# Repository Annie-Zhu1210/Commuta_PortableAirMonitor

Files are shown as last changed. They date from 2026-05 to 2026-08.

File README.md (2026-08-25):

# Commuta — A Portable IoT Air Quality Monitor

**A wearable, battery-powered device that measures your personal air quality on the go — built to capture fine-particle (PM) exposure during everyday journeys on the London Underground.**






<p align="center">
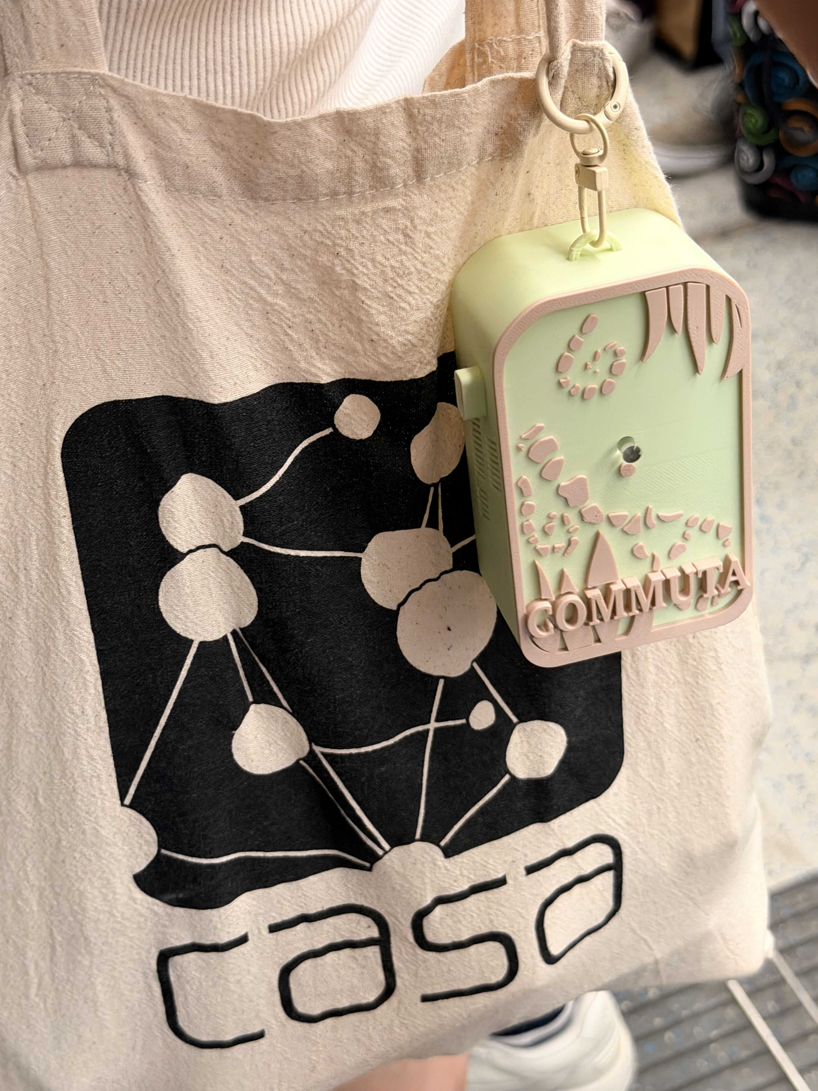
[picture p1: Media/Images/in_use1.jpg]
Commuta device
  
</p>

---

## Overview

Commuta is a compact, self-contained air quality monitor designed to be carried through a daily commute. Most air quality data comes from fixed street-level stations, which say little about what a person actually breathes underground, on a platform, or inside a carriage. Commuta closes that gap: it logs particulate matter and supporting environmental readings continuously as you travel, then streams the data to a companion iOS app over Bluetooth Low Energy.

The result is a personal, location-aware record of exposure — the kind of data that lets you see, for example, how a deep, older Underground line compares to a sealed, modern one.

## Key Features

- **Personal PM monitoring** — measures PM1, PM2.5, PM4 and PM10 with a laser particle sensor.
- **Full environmental context** — also logs CO₂, temperature, humidity, VOC and NOx indices, and barometric pressure.
- **Fully portable** — runs off an onboard rechargeable LiPo battery, no wires or phone tether needed to collect data.
- **On-device logging** — data is buffered to flash storage, so nothing is lost if the phone is out of range.
- **BLE companion app** — a Flutter iOS app with a live air quality score, per-pollutant bands and health advice, maps, history charts, and CSV export ([full feature list](commuta_app#features)).
- **Discreet by design** — a custom 3D-printed enclosure and minimal indicator LEDs, intended to be worn unobtrusively.

## How It Works

Commuta is a three-part system: the **device** senses and logs, the **app** receives and tags, and the **analysis pipeline** turns raw logs into exposure insights.

<p align="center">
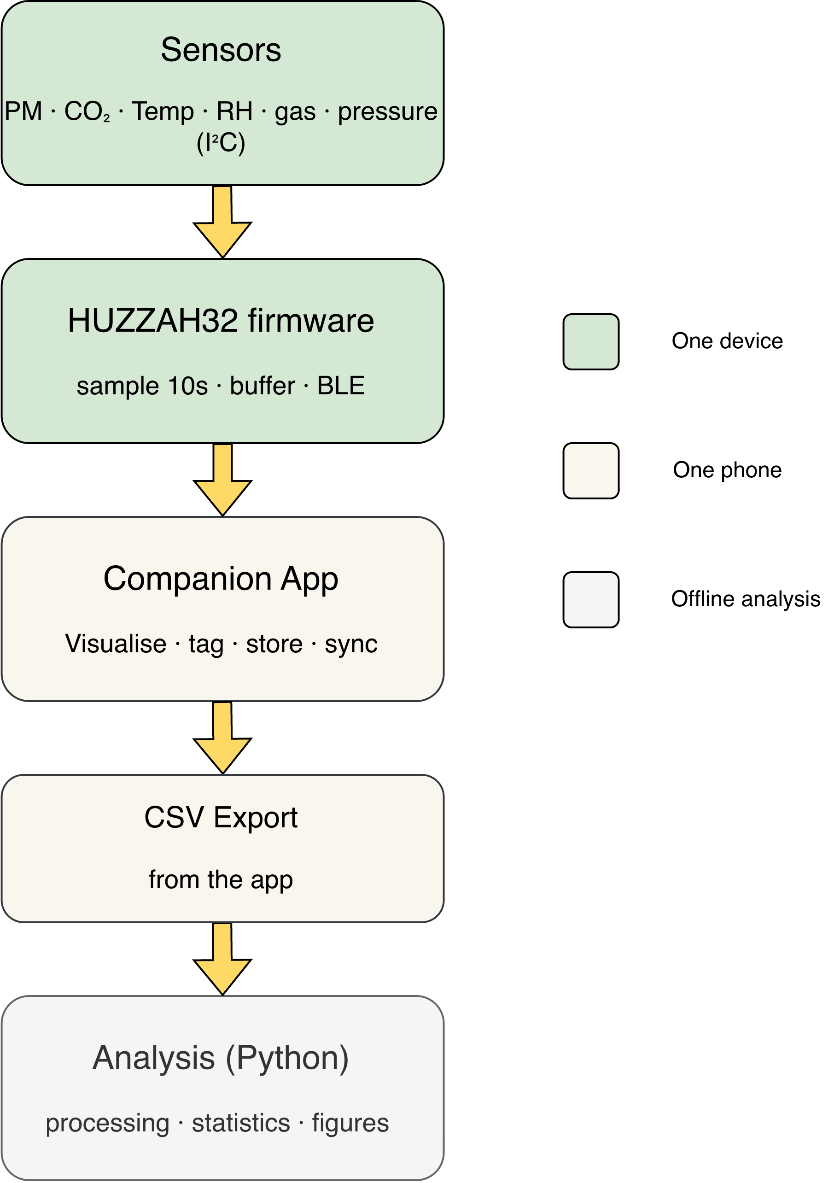
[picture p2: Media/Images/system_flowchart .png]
System architecture
  
</p>

## Hardware

The device is built around an ESP32 microcontroller with a stack of I²C sensors and a boosted power supply for the particle sensor.

| Component | Part | Role |
|---|---|---|
| Microcontroller | Adafruit HUZZAH32 (ESP32) | Sensing, logging, BLE |
| Particulate matter | Sensirion **SPS30** | PM1 / PM2.5 / PM10 |
| CO₂ & climate | Sensirion **SCD40** | CO₂, temperature, humidity |
| Gas indices | Sensirion **SGP41** | VOC index, NOx index |
| Pressure | Infineon **DPS368** | Barometric pressure |
| Power | 2000 mAh LiPo + MT3608 boost | Portable supply (5 V for the SPS30) |

<p align="center">
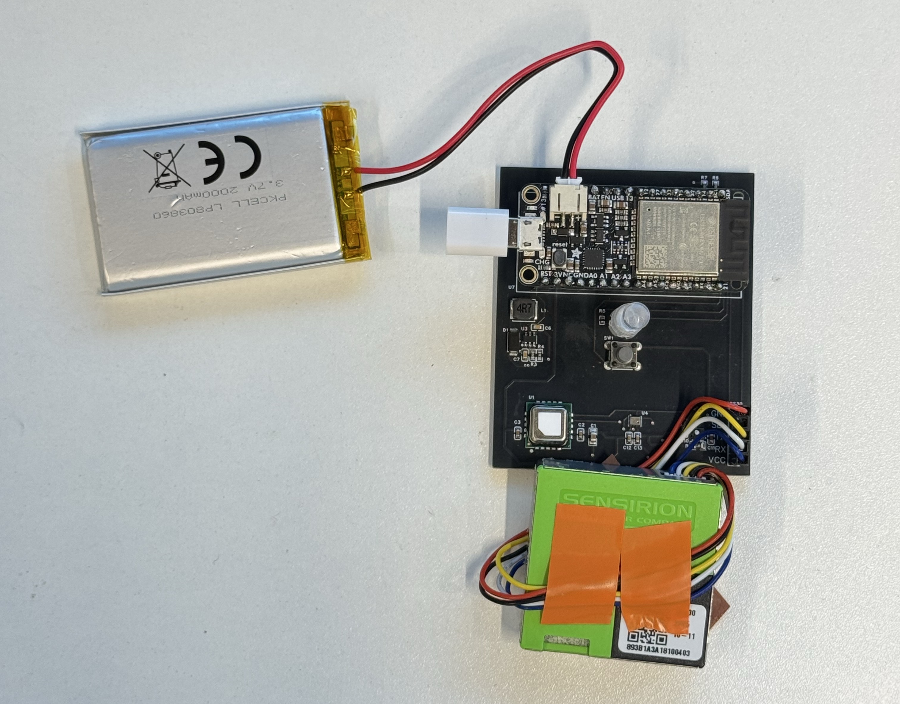
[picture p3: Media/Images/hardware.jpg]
Assembled hardware
  
</p>

## Enclosure

A custom enclosure houses the electronics and battery in a wearable form factor. CAD and printable files live in [`/enclosure`](enclosure).

<p align="center">
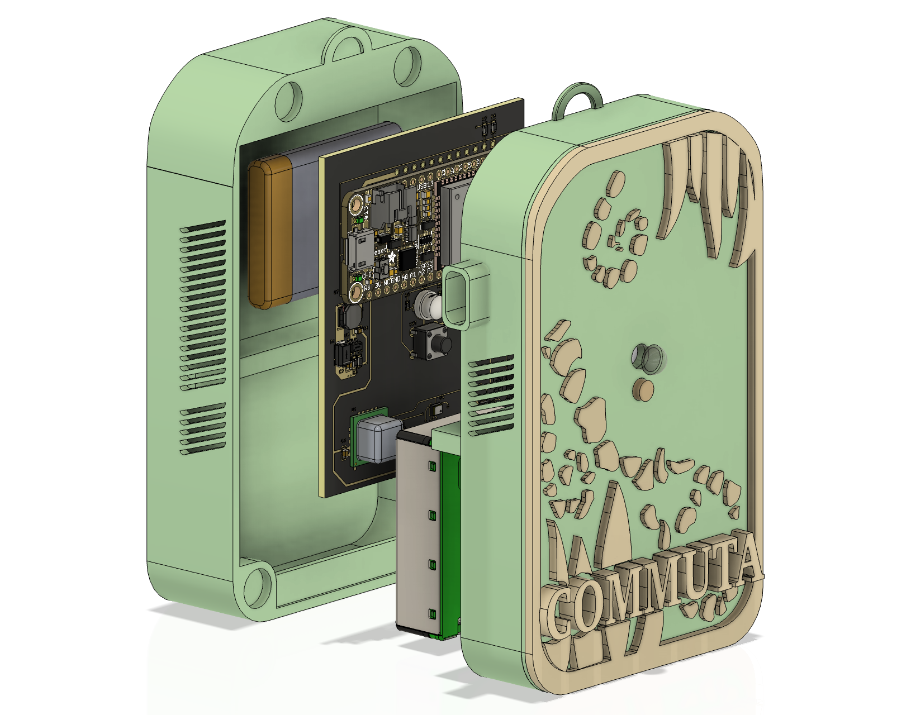
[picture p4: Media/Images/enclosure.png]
Enclosure
  
</p>

## Repository Structure

| Folder | Contents |
|---|---|
| [`Device/`](Device) | `Commuta_code/`: main device firmware — sensor drivers, logging, and BLE communication (C++ / Arduino). `PCB/`: schematic and PCB gerber files. Plus the [Button & LED reference](Device/Button%26LED.md). |
| [`commuta_app/`](commuta_app) | The Flutter iOS companion app. **See its own [README](commuta_app) for features, architecture, and setup.** |
| [`enclosure/`](enclosure) | 3D-printable enclosure — see its [README](enclosure) for what to print and the design history. |
| [`data/`](data) | Field-study dataset: untouched raw device exports and a fully reproducible raw → clean pipeline — see its [README](data). |
| [`visualisation/`](visualisation) | Analysis scripts and figures for the Underground PM2.5 case study — see its [README](visualisation) for the script → figure map. |
| [`Battery/`](Battery) | LiPo battery discharge characterisation — data, script, and [report](Battery/battery_report.md). |
| [`test_SPS30/`](test_SPS30) | Standalone bring-up sketch for the SPS30 particle sensor. |
| [`test_PMS5003/`](test_PMS5003) | Early sensor evaluation sketch (PMS5003). |
| [`Media/`](Media) | Photos, diagrams, and figures. |

## Getting Started

### Device firmware
1. Open the sketch in [`Device/Commuta_code/`](Device/Commuta_code) with the Arduino IDE.
2. Install the ESP32 board package and the required Sensirion sensor libraries.
3. Copy `secrets_example.h` to `secrets.h` and generate your own BLE UUIDs (instructions inside the file). The same UUIDs go into the app's `ble_uuids.dart`.
4. Select the **Adafruit HUZZAH32 (ESP32)** board, connect over USB, and flash.

### Companion app
The iOS app is in [`commuta_app/`](commuta_app). Build and setup instructions are documented in that folder's README.

## Case Study: PM2.5 on the London Underground

As its first real-world deployment, Commuta was carried across six London Underground lines to study how line type and platform ventilation design affect commuters' PM2.5 exposure. The full chain is in this repo and is reproducible end to end:

1. **Collect** — the device logs readings during journeys; the app tags stations and exports CSVs.
2. **Clean** — [`data/`](data) holds the untouched raw exports and a rule-driven pipeline (`python data/process_data.py`) that regenerates the clean dataset from them.
3. **Analyse** — [`visualisation/`](visualisation) turns the clean data into the study's figures (`python visualisation/step0_dataprep.py`, then any figure script).

<p align="center">
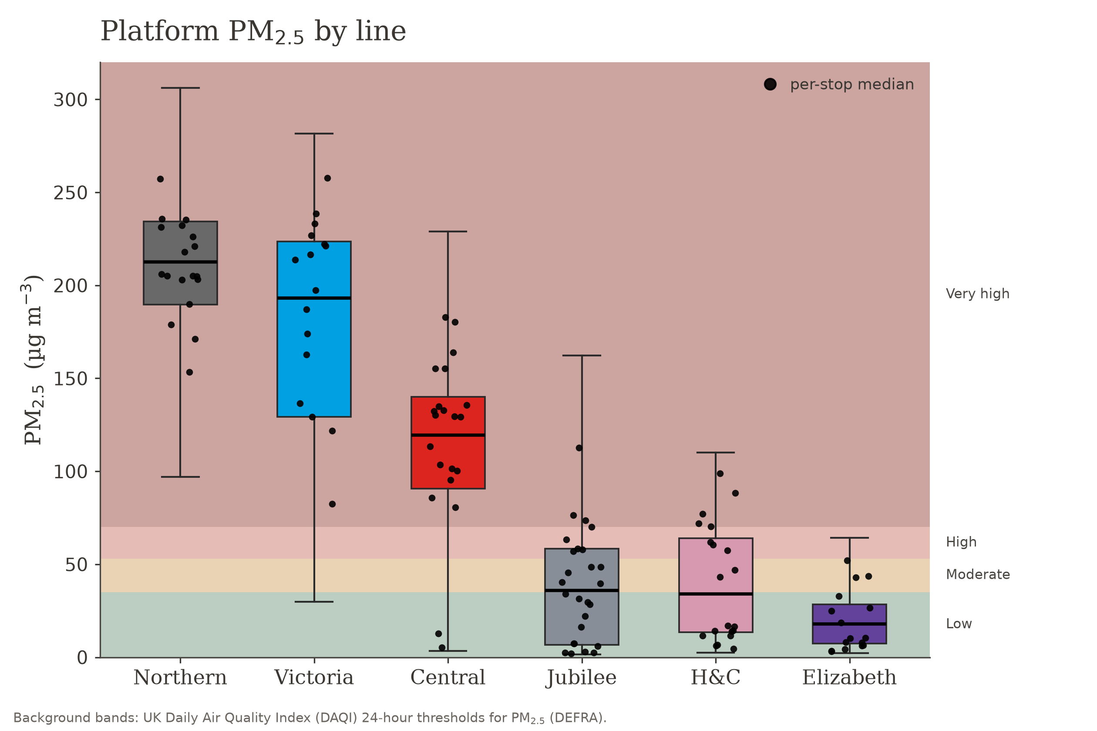
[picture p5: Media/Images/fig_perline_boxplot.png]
Platform PM2.5 exposure comparison across Underground lines
  
</p>

## About the Project

Commuta was developed by Annie Zhu as a prototype on the **Connected Environments** programme at **UCL's Centre for Advanced Spatial Analysis (CASA)**; the Underground case study above formed the research component.

🔗 **Project site:** https://annie-zhu1210.github.io/commuta

## Acknowledgements

- Sensor integration benefited from technical guidance from Sensirion support.

---

<p align="center"><i>Built by Annie Zhu · UCL CASA</i></p>

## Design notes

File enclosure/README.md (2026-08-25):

# Commuta Enclosure

3D-printable enclosure for the Commuta device — a compact, wearable case that houses the ESP32, sensor stack, boost converter, and 2000 mAh LiPo battery, with openings for airflow to the particle sensor, the USB-C charging port, and the single control button.

<p align="center">
  Commuta enclosure
</p>

## What to print

Everything you need for a complete enclosure is in [`final_version/`](final_version):

| File | Part |
|---|---|
| `FinalVersion_Top.stl` | Top shell |
| `FinalVersion_Bottom.stl` | Bottom shell |
| `ButtonCover3.stl` | Button cap for the power/status button |
| `TypeC.stl` | USB-C port cover |
| `FinalVersion_浮雕.3mf` | Embossed (relief) logo variant of the shell — a multi-body 3MF for printing the raised Commuta wordmark, e.g. in a second colour |

The `.3mf` file preserves the separate relief bodies, so open it in your slicer directly (rather than converting to STL) if you want to assign the embossed text its own colour or material.

Printed in PLA with standard settings; no supports are required for the shells in their natural print orientation. The two shells close around the electronics, so check the fit of your assembled stack before committing to long prints.

## Design history

Folders `version1/` through `version9/` document the design's evolution and are kept for reference — none of them are needed to build the device:

- **version1–2** — first fit tests: single shell, then a split top/bottom design.
- **version3** — confirmed the approximate dimensions and necessary openings.
- **version4–5** — tested connection configurations using two sets and four sets of magnets, respectively.
- **version6** — refined shells plus the first embossed-logo (浮雕) experiments as separate relief bodies.
- **version7-10** — button cap and adaptor cover iterations; adjusted button and LED openings dimensions.

## Related

- [Hardware overview](../README.md#hardware) — what goes inside
- [Button & LED reference](../Device/Button%26LED.md) — how the single button and bi-colour LED work

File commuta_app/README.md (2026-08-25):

# Commuta App

**The companion app for the Commuta portable air quality monitor — live readings, maps, history, and health guidance, built with Flutter.**






The Commuta app pairs with the Commuta device over Bluetooth Low Energy and turns its raw sensor stream into something you can act on: an at-a-glance air quality score, per-pollutant bands and health advice, a map of where you breathed what, and a browsable history of every journey.

<p align="center">
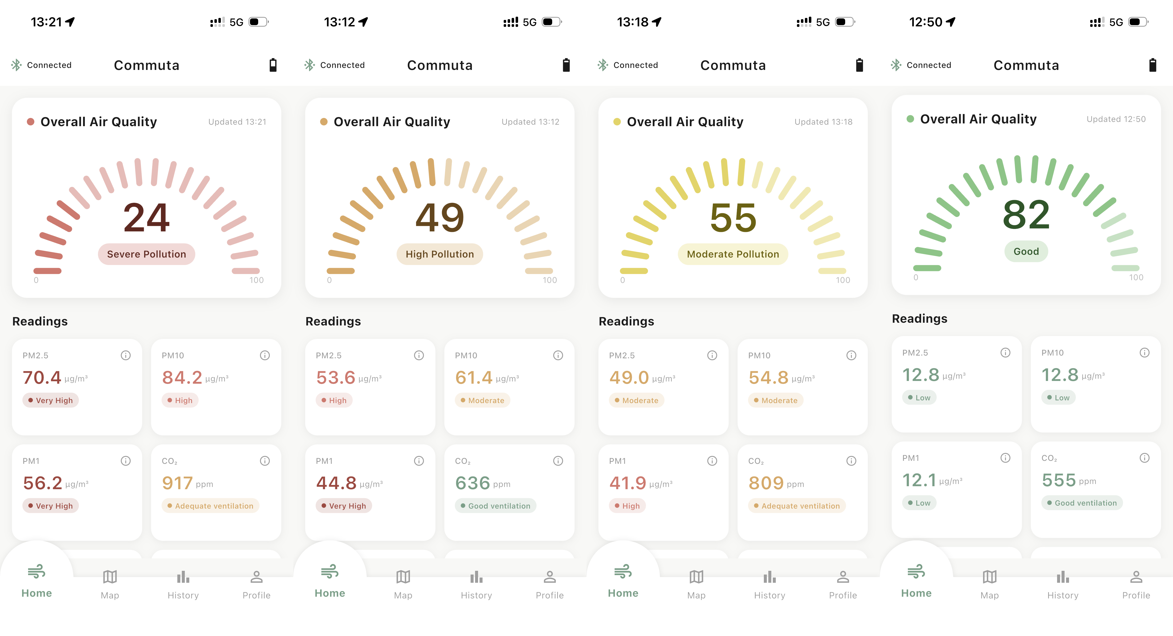
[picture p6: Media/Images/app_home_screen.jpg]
Commuta app Home screen
  
</p>

---

## Features

### Live monitoring (Home)

- **Hero Score** — a single 0–100 score (higher is cleaner) summarising the current reading, with a colour-coded arc gauge and a plain-English descriptor (*Good*, *Moderate Pollution*, *High Pollution*, *Severe Pollution*). The score follows the worst-metric-drives-the-score principle used by the UK DAQI and US EPA AQI. The full algorithm is documented in [`docs/hero_score_algorithm.md`](docs/hero_score_algorithm.md).
- **Live metric cards** for every sensor channel: PM1, PM2.5, PM4, PM10, CO₂, temperature, humidity, barometric pressure, VOC index, and NOx index.
- **Band scales** — each pollutant card shows where the current value sits on its own band scale (*Low / Moderate / High / Very High*), aligned with UK DAQI band boundaries.
- **Health recommendations** — tapping the ⓘ on a metric card opens an info sheet explaining what the metric is and what to do at the current level, updating live as new readings arrive.
- **Local context cards** — the nearest **UK DAQI** value from the London Air Quality Network (LAQN) and current **local weather** from OpenWeather, so device readings can be compared against the official outdoor picture.

<p align="center">
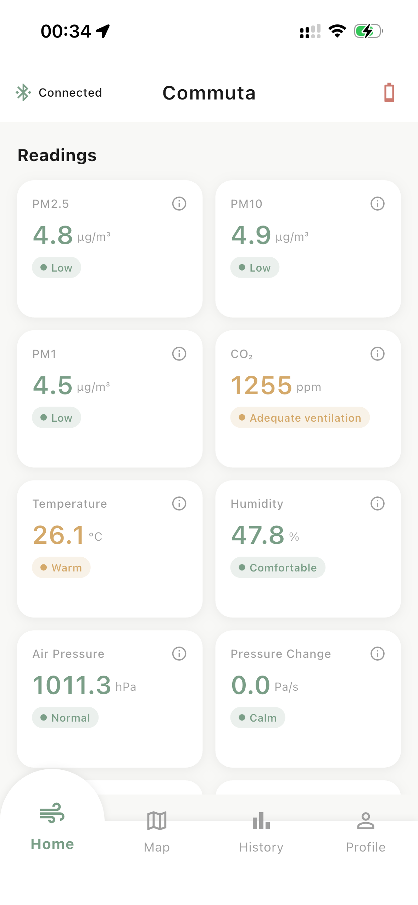
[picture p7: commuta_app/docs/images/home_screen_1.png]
Home screen data cards
  
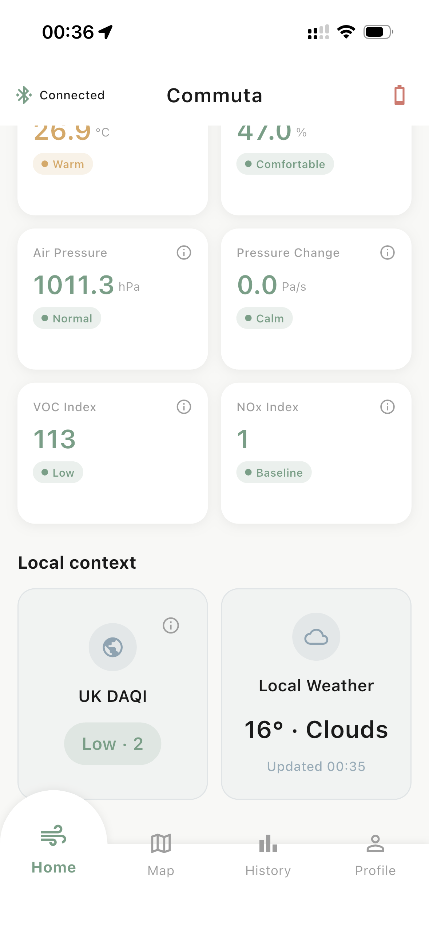
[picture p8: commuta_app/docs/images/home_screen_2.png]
More Home screen data cards
  
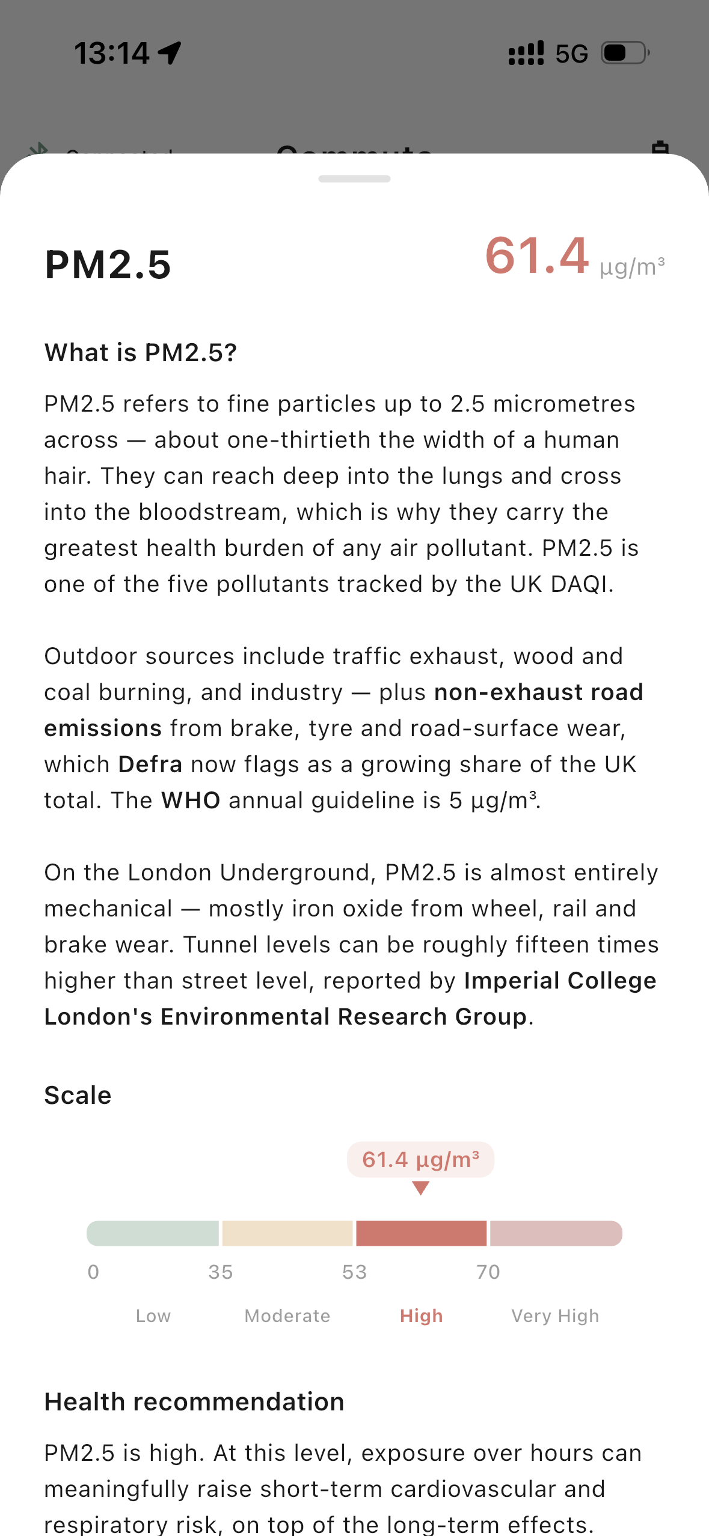
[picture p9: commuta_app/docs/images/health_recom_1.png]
Data cards health recommendation
   
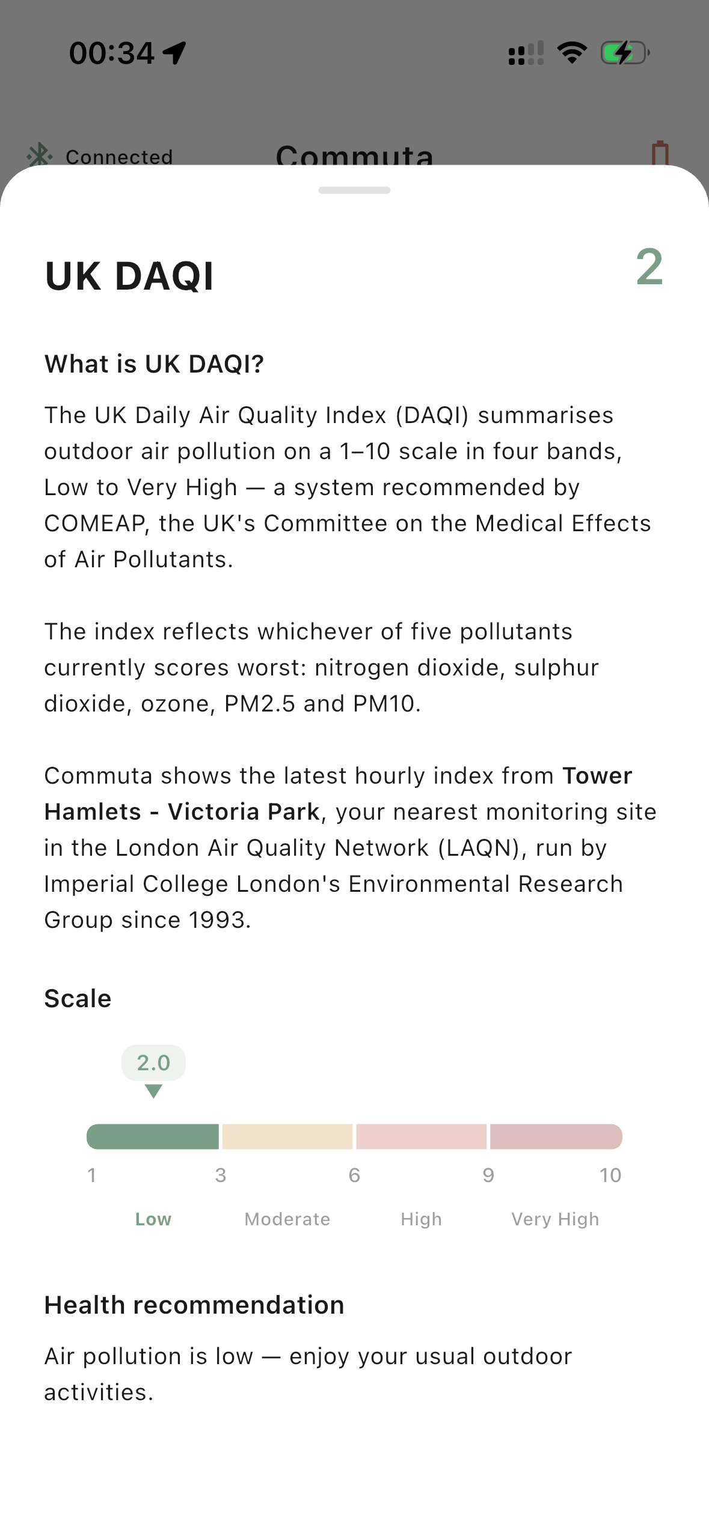
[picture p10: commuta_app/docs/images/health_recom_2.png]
More data cards health recommendation
  
</p>

### Maps

- **Google Map view** — plots your path as you move, dropping colour-coded markers along the route; tapping a marker shows the detailed air quality reading captured at that point.
- **TfL Underground map view** — a custom-painted Tube map showing stations where air quality data has been collected, with per-station readings. Station dwell detection and classification happen automatically in the background.
- A floating toggle switches between the two views; both stay mounted so camera position, markers, and selections survive switching tabs.

<p align="center">
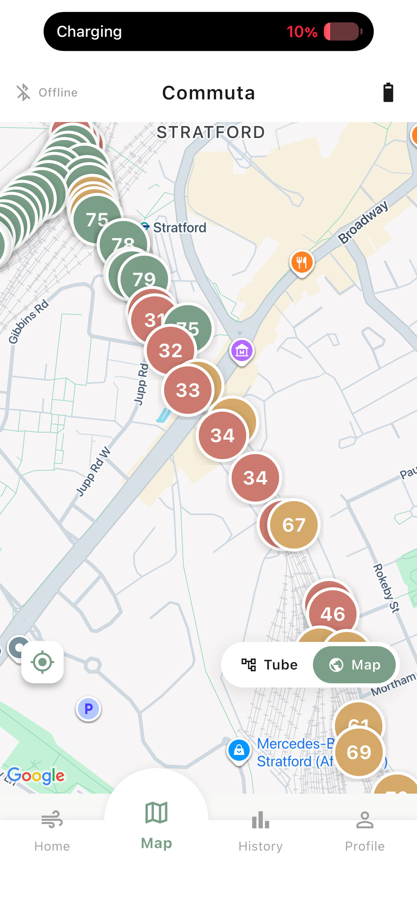
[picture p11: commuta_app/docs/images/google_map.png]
Google Maps screen
  
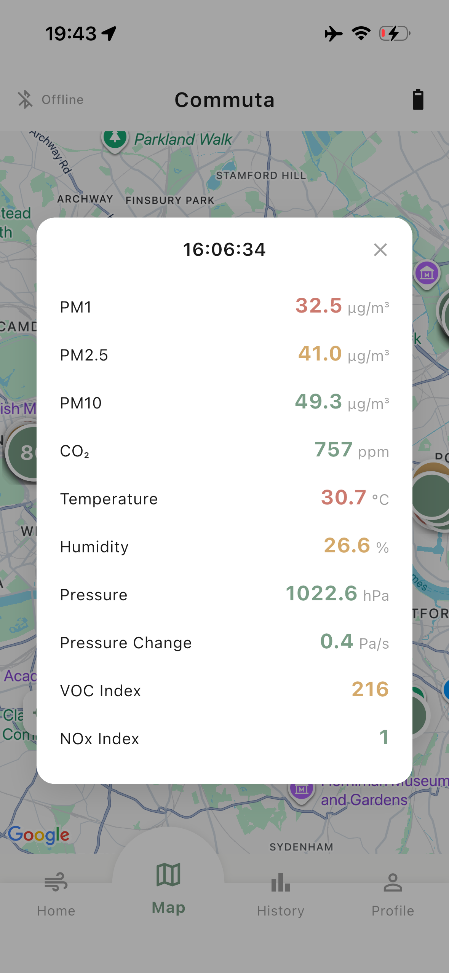
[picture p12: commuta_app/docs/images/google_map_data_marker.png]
Detailed data card on the Google Maps screen
  
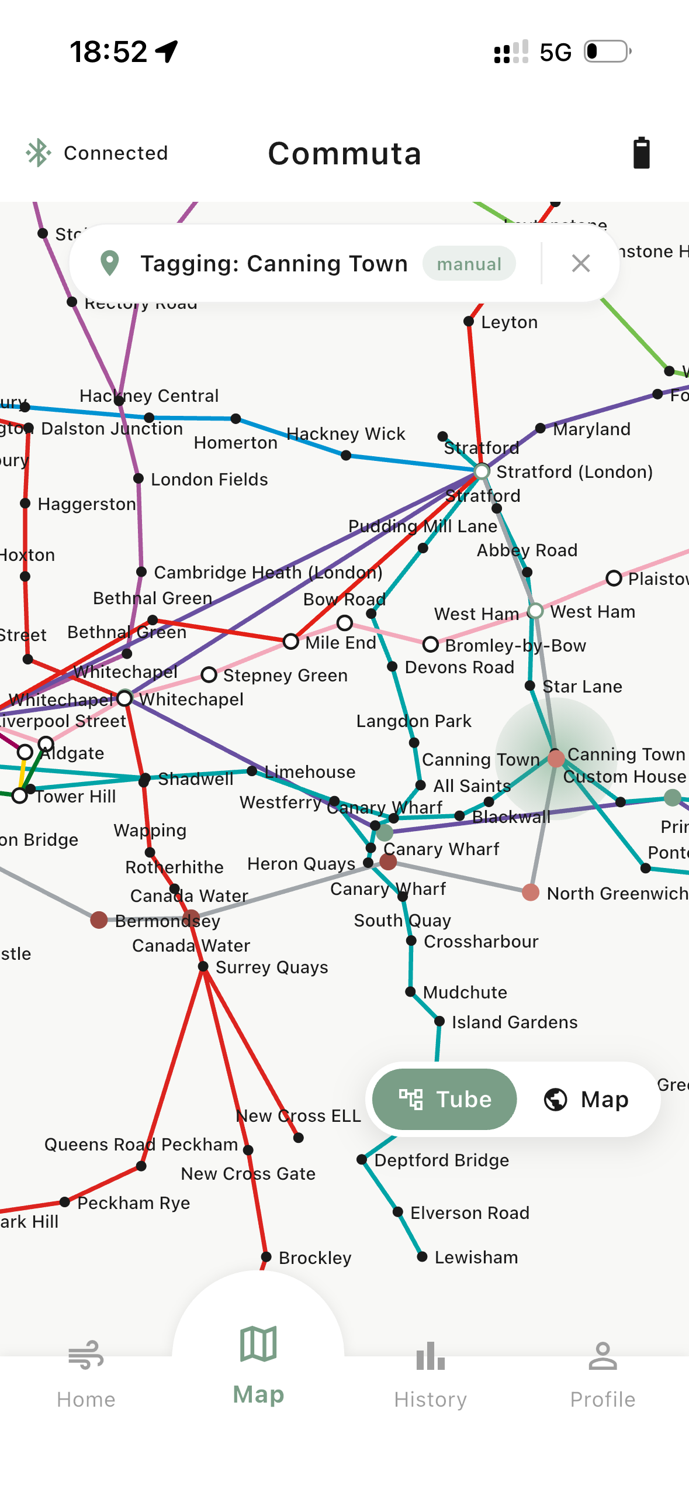
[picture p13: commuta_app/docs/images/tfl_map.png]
TFL map with manual station selection
   
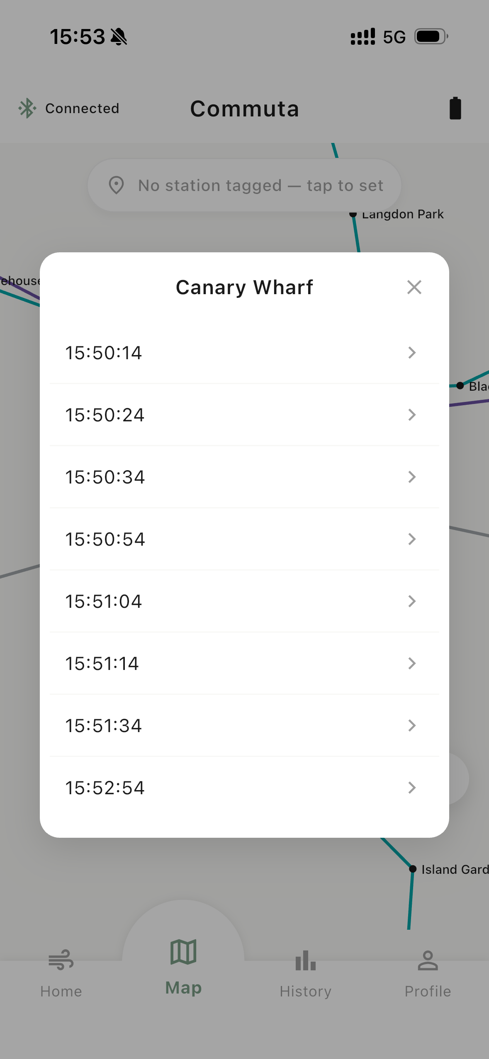
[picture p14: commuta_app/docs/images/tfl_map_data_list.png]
Tap a station on the TFL map to see all data collected at this station
  
</p>

### History

- **Daily view** — line charts (fl_chart) of any day's readings, per metric.
- **Weekly view** — aggregated week-at-a-glance charts, navigable by week.
- All readings are persisted on-device in a local SQLite database (drift), so history survives app restarts and works fully offline.

<p align="center">
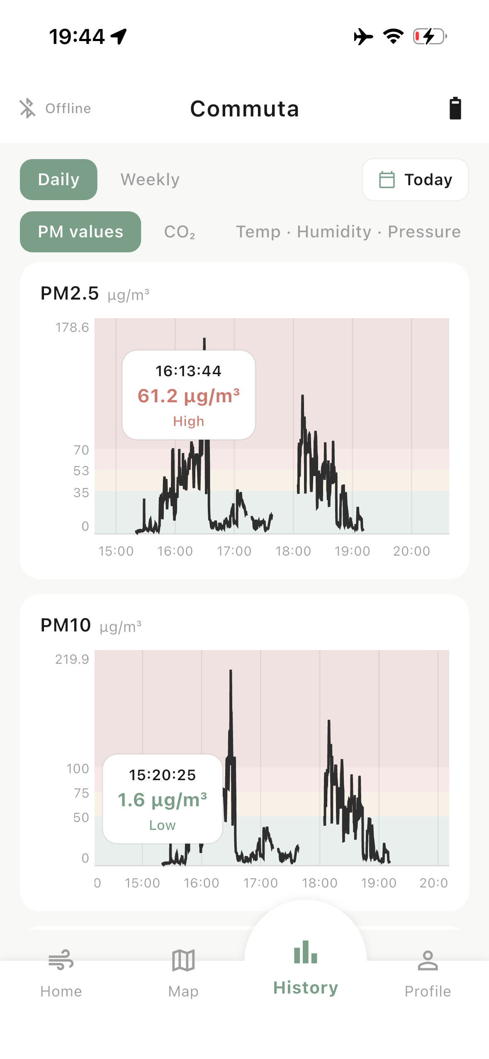
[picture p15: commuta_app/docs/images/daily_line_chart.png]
Daily view of historical data
  
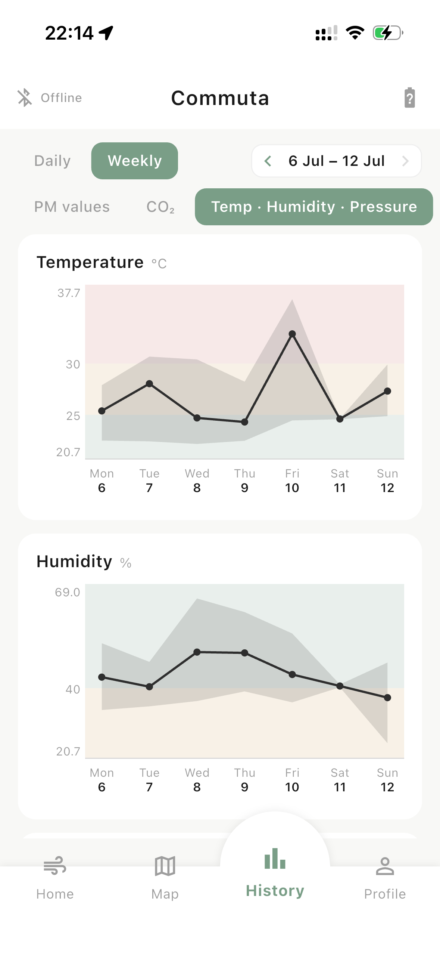
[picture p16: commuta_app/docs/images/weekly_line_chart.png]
Weekly view of historical data
  
</p>

### Device pairing & sync

- **Scan & pair screen** — discovers nearby Commuta devices over BLE and manages the connection lifecycle (scanning → connecting → connected → syncing).
- **Buffered sync** — the device logs to its own flash storage while out of range; on reconnect, the app pulls the buffered backlog so no data is lost.
- Clear adapter-state handling: the UI distinguishes "Bluetooth is off" and "permission needed" from ordinary scan states.

<p align="center">
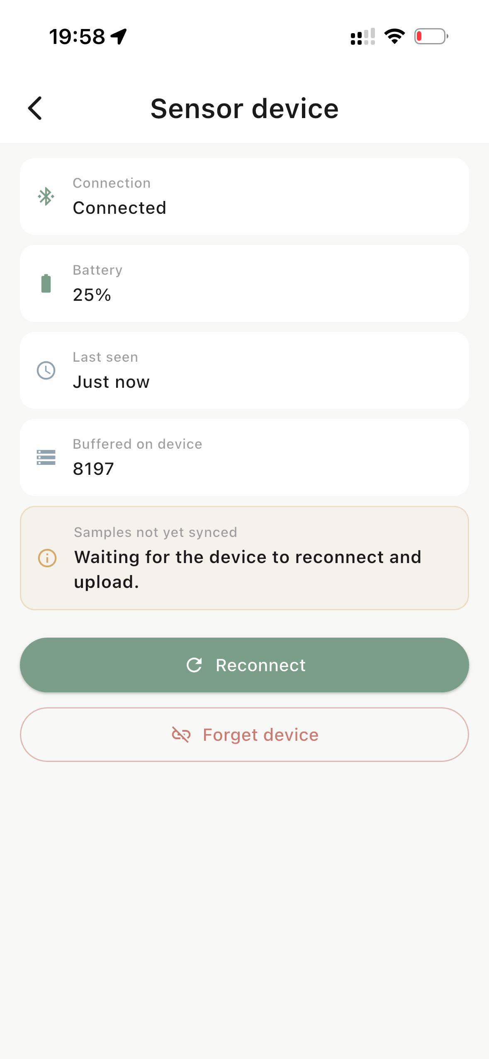
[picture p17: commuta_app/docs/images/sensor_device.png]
Sensor device screen of the app
  
</p>

### Data export & profile

- **CSV export** — export *all readings*, *today's readings*, or the *battery characterisation log* as CSV via the iOS share sheet.
- **Device section** — connection status and device management.
- **Coming soon** (stubbed in the UI): **Account** (sign-in and cloud sync, Firebase-ready) and **Alerts** (custom threshold-based phone notifications).

<p align="center">
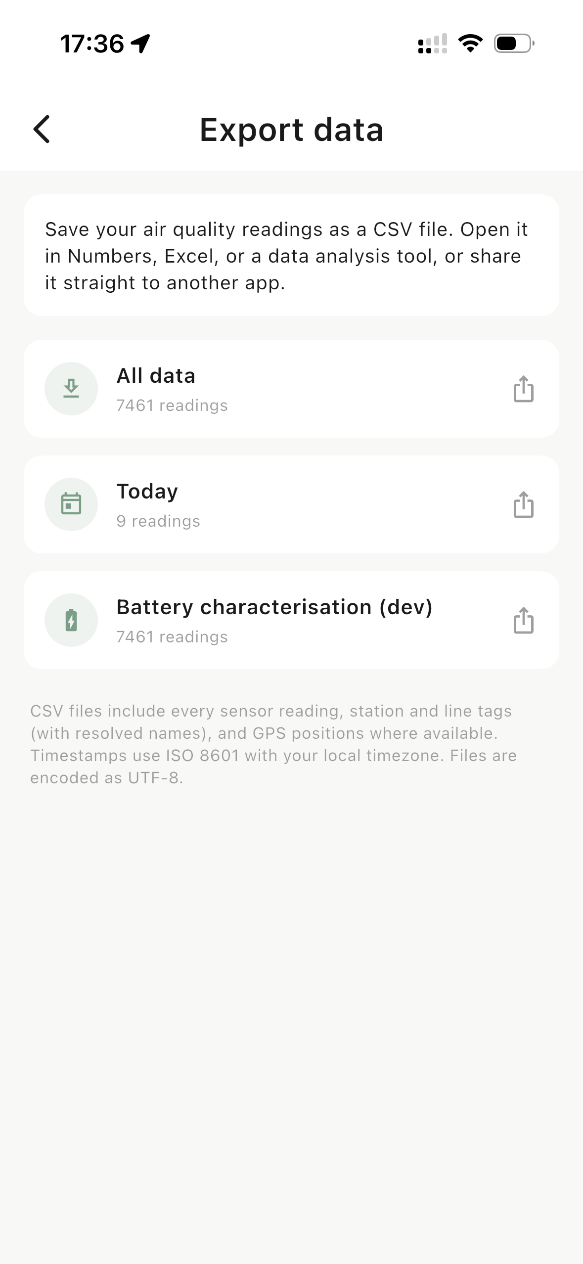
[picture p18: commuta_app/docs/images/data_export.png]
Data export options
  
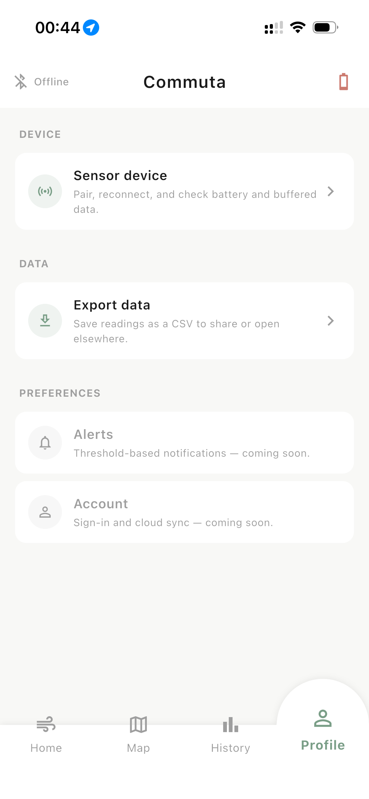
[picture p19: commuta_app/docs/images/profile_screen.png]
Profile screen
  
</p>

## Architecture

```
lib/
├── main.dart / app.dart      app entry, theming, bottom navigation
├── core/
│   ├── constants/            API keys & BLE UUIDs (gitignored; examples committed)
│   └── utils/                DAQI band logic, battery state-of-charge
├── data/                     models, drift database, datasources
├── screens/
│   ├── home/                 hero card, metric grid, DAQI & weather cards
│   ├── map/                  Google Map view, TfL map view, station picker
│   ├── history/              daily & weekly chart views
│   ├── scan_pair/            BLE discovery and pairing
│   └── profile/              device section, data export, preferences
├── services/                 the app's working core — BLE connection,
│                             readings repository, hero score, dwell
│                             detection, station classification, TfL map
│                             data, location, CSV export, local context
│                             (LAQN + OpenWeather)
└── widgets/                  hero AQI card, metric cards, band scales,
                              info sheets, nav bar, status banners
```

Key design points: the BLE layer is wrapped behind a library-agnostic `DeviceConnection` interface (so the app can run against a mock device without hardware), readings flow through a single `ReadingsRepository` backed by drift/SQLite, and all screens stay mounted in an `IndexedStack` so state survives tab switches.

## Getting started

### Prerequisites

- Flutter SDK ^3.10 (Dart 3)
- Xcode (the prototype targets iOS; other platform folders exist but are untested)
- A Commuta device (optional — the app includes a mock connection for UI development)

### Setup

Four config files are gitignored and must be created from their committed examples:

1. **API keys (.env)** — copy `.env.example` to `.env` and fill in:
   - `TFL_API_KEY` from https://api-portal.tfl.gov.uk/
   - `OPENWEATHER_API_KEY` from https://openweathermap.org/api
2. **OpenWeather key (Dart)** — copy `lib/core/constants/api_keys.example.dart` to `api_keys.dart` in the same folder and add your OpenWeather key. (LAQN needs no key.)
3. **BLE UUIDs** — copy `lib/core/constants/ble_uuids.example.dart` to `ble_uuids.dart` and fill in the same UUIDs used in the device firmware's `secrets.h` (see [`../Device/Commuta_code/secrets_example.h`](../Device/Commuta_code/secrets_example.h)). A mismatched service UUID makes scans silently find nothing.
4. **Google Maps keys** — copy `ios/Flutter/Secrets.xcconfig.example` to `Secrets.xcconfig` (and, for Android, `android/secrets.properties.example` to `secrets.properties`) and add your Google Maps API key(s).

Then:

```bash
flutter pub get
flutter run          # with an iOS device/simulator connected
```

### Refreshing TfL data

Station and line geometry for the Tube map lives in `assets/tfl/`. To refresh it from the TfL API:

```bash
dart run scripts/refresh_tfl_data.dart
```

## Related documentation

- [Hero Score algorithm](docs/hero_score_algorithm.md) — how the 0–100 score and descriptors are computed
- [Device firmware](../Device) — the ESP32 firmware this app talks to
- [Repository overview](../README.md) — the full Commuta system

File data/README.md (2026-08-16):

# Commuta dataset

Personal PM-exposure measurements collected on six London Underground lines with the
Commuta portable air-quality monitor. This folder holds the raw exports, the
transformation that produces the analysis-ready dataset, and that dataset itself.

## Provenance and reproducibility

The raw exports in `raw/` are the CSV files produced by the Commuta app, byte-for-byte,
and are **never edited**. All cleaning is done by `process_data.py`, driven entirely by
two small, human-readable metadata files. Anyone can regenerate the clean dataset from
the untouched raw data with a single command:

```
python process_data.py
```

Because every change is expressed as an explicit, auditable rule in the metadata files
(not a manual edit to a data cell), the raw -> clean transformation is fully
reproducible. This is the integrity guarantee: the clean dataset was not hand-assembled.

## Folder layout

```
data/
├── raw/                     five app exports, untouched
├── metadata/
│   ├── segments.csv         one row per journey: sequence range -> line, group, direction
│   └── corrections.csv      station-tag fixes (clear_tag / set_tag / drop)
├── clean/
│   └── commuta_clean.csv    output of process_data.py
├── process_data.py          the pipeline
└── README.md
```

## What cleaning does — and does not — change

Cleaning changes only three things:

1. **Station tags** are corrected per `corrections.csv`.
   - `clear_tag` removes a stale/false GPS auto-tag (a previous station briefly
     re-detected while in transit).
   - `set_tag` restores the correct tag on rows that arrived as buffered data and so
     missed the platform tag that was selected in the app.
2. **Row inclusion**: only rows inside a journey defined in `segments.csv` are kept.
   Everything else (device warm-up before the first station, interchange walks between
   lines) is dropped. `process_data.py` prints every dropped range so each exclusion is
   visible and intentional.
3. **Labels are added**: `line_name`, `group` (busier / quieter, from observed
   conditions), `direction`, `segment_id`, `day`, `location_type`, `source_file`.

Cleaning **never alters sensor values**. PM, CO2, temperature, humidity, pressure and
gas readings are carried through at full precision exactly as recorded. Humidity
correction (Crilley et al.), any rounding, and all analysis are done downstream in the
analysis notebook, so raw research values are preserved in the clean file too.

## Key notes

- **Keying** is `(source_file, sequence_number)`. File 1's sequence numbers overlap
  file 2's (the counter was reset by an early code change), so sequence number alone is
  not unique across files.
- **File 1** was recorded before the code change that added the DPS368 secondary-
  temperature column, so its `DPS_tem` is blank; its `temperature` column is SCD40, the
  same source as every other file, so temperature is directly comparable throughout.
- **`day`** is taken from the filename date, not the row timestamp, because file 1's
  clock was set during a home test of the app.
- **`location_type`** is `platform` where a (corrected) station tag is present and
  `in_train` for the untagged stretches between stations — both are valid measurements.

## Columns in `commuta_clean.csv`

`source_file, day, sequence_number, timestamp, segment_id, line_name, group, direction,
location_type, station_id, station_name, pm1, pm25, pm10, co2, temperature, DPS_tem,
humidity, pressure, pressure_change_pa_per_sec, nox, tvoc, voc_raw, nox_raw,
source_flag, gps_lat, gps_lng`

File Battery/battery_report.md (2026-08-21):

# Commuta battery discharge characterisation

Test run: **2026-08-01 00:17** to **2026-08-02 00:17 (UTC+01:00)**  
Wall-clock span: 24.00 h. **Active sampling runtime: 12.76 h** — the cell was actually under load for this long. The two periods when the device was switched off (see §1) do not count.

> **Correction notice.** An earlier version of this report used wall-clock time as the discharge axis, which included the device-off periods and produced a fake voltage plateau. This version uses sequence-based active time, which is the correct denominator for a discharge curve. All lookup values and the stop-threshold recommendation have changed as a result.

## 1. Data quality

- **Rows recorded:** 4,165.
- **Single power session:** one `boot_epoch` throughout — device did not reboot even across the off-periods (the ESP32 sequence counter is restored from NVS on power-up).
- **Voltage range:** 3860 mV at first recorded sample, peak 3931 mV shortly after, ending at 2377 mV when the device died.

### Device-off periods

The device was switched off for these intervals. The voltage was not actually flat during them — the cell was simply not being sampled. On the active-time axis these intervals collapse to zero width.

| Wall-clock start | Wall-clock end | Duration | Voltage before → after |
|---|---|---|---|
| 03:53 | 14:11 | 618.2 min | 3599 mV → 3609 mV |
| 20:34 | 21:30 | 56.3 min | 3244 mV → 3251 mV |

### Data-loss periods (device on, samples never reached CSV)

| Active-time window | Missing samples | Voltage before → after |
|---|---|---|
| 7.84 h – 7.87 h | 9 | 3341 mV → 3323 mV |
| 11.15 h – 12.29 h | 412 | 3154 mV → 3035 mV |
| 12.34 h – 12.35 h | 4 | 3016 mV → 3009 mV |

These samples are irrecoverable — the LOWESS fit bridges the window smoothly using the voltages either side, which is safe given the slowly-varying discharge in that region.

## 2. Method

- **Axis:** sequence-based active time. Each sample carries a monotonically incrementing `sequence_number` that only advances while the device is actually sampling, so `(sequence_number − first_sequence) × 10 s` gives the true elapsed runtime under load.
- **Smoother:** locally-weighted regression (LOWESS), bandwidth `frac = 0.05`. Forced non-increasing via cumulative-minimum for percentage inversion.
- **Reference:** isotonic regression (guaranteed monotonic) is overlaid on the chart as a sanity check.
- **Gap handling:** the two device-off intervals do not exist on this axis at all. The data-loss intervals are bridged by the LOWESS fit anchored on the samples either side.

## 3. Discharge phases

| Phase | Active-time window | Voltage window | Mean slope |
|---|---|---|---|
| **Initial drop** | 0.00 h – 0.30 h | 3894 mV → 3843 mV | -167.8 mV/h |
| **Gentle decline** | 0.30 h – 11.15 h | 3843 mV → 3168 mV | -62.3 mV/h |
| **Cutoff** | 11.15 h – 12.76 h | 3168 mV → 2719 mV | -277.8 mV/h |

Interpretation:

- **Initial drop.** The characteristic post-full-charge relaxation — the surface-charge component decays quickly under load.
- **Gentle decline.** The long middle where the cell empties at a steady rate. Voltage tracks state-of-charge reasonably well here — unlike the fake plateau in the earlier report, there is no true flat region in this cell's discharge.
- **Cutoff.** Steep terminal drop of several hundred mV/hour. From here the cell has very little useful capacity left.

## 4. Voltage → percentage-remaining lookup

Percentages are computed as `1 − t(V) / active_total`, where `t(V)` is the active time at which the fitted curve crosses voltage `V`, and `active_total` = 12.76 h. Full 50 mV lookup is in `voltage_percentage_lookup.csv`.

| Voltage | Active time reached | Percent remaining | Active hours left |
|---|---|---|---|
| 3.90 V | 0.00 h | 100% | 12.8 h |
| 3.80 V | 0.65 h | 95% | 12.1 h |
| 3.70 V | 1.88 h | 85% | 10.9 h |
| 3.60 V | 3.58 h | 72% | 9.2 h |
| 3.50 V | 5.12 h | 60% | 7.6 h |
| 3.40 V | 6.62 h | 48% | 6.1 h |
| 3.35 V | 7.57 h | 41% | 5.2 h |
| 3.30 V | 8.64 h | 32% | 4.1 h |
| 3.20 V | 10.70 h | 16% | 2.1 h |
| 3.10 V | 11.46 h | 10% | 1.3 h |
| 3.00 V | 11.91 h | 7% | 0.8 h |
| 2.90 V | 12.34 h | 3% | 0.4 h |
| 2.80 V | 12.59 h | 1% | 0.2 h |
| 2.70 V | 12.76 h | 0% | 0.0 h |
| 2.60 V | 12.76 h | 0% | 0.0 h |
| 2.50 V | 12.76 h | 0% | 0.0 h |
| 2.40 V | 12.76 h | 0% | 0.0 h |

## 5. Recommendation on the stop threshold

- At **3.30 V**, the fitted curve gives **≈ 32% remaining** — reached after **8.6 hours** of active use, with roughly **4.1 hours** of runtime still available before the cell would die.
- Selected reference points for context:
  - 3.60 V ≈ 72% remaining
  - 3.50 V ≈ 60% remaining
  - 3.40 V ≈ 48% remaining
  - 3.20 V ≈ 16% remaining

**Practical runtime with a 3.30 V manual stop: ~8.6 hours of active use per charge.** This is enough for a single exhibition day but not two — plan on charging the cell nightly rather than trying to stretch a charge across consecutive collection days. Stopping earlier (e.g. at 3.40 V, ≈ 48%) buys headroom for cell longevity at the cost of shorter runtime per charge.

- No firmware low-voltage cutoff currently exists; this test drove the cell to 2377 mV (the point at which the device could no longer boot).

## 6. Caveats

- Percentages here are relative to *this specific test's* active runtime under the observed load. Real-world runtime will vary with BLE activity, temperature, cell ageing, and whether the app is foregrounded (buffering vs streaming).
- **The in-app battery indicator uses the earlier (wrong) lookup table** and has not been updated. It will show systematically lower percentages than reality in the mid-voltage range (e.g. 21% displayed at 3.30 V rather than ~32%, 29% at 3.40 V rather than ~48%). This is the conservative direction — the app under-reports, prompting earlier charging — but is worth logging for completeness.
- The full-charge peak of ~3.93 V (rather than the ~4.20 V typical of a single-cell LiPo) is worth logging for the dissertation. It doesn't affect the validity of the percentage mapping in-app so long as the same ADC reading path is used at runtime, but the ADC calibration or charging IC set-point may be worth checking after the exhibition.

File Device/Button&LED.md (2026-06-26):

# Commuta — Button & LED Reference

Commuta has one button and one bi-colour LED (red, green, and yellow by combining the two). All interaction is through this single button.

## Turning the device on

Press and hold the button. After about 2 seconds, the **red LED turns on**. Release the button.

The red LED stays on while sensors warm up (about 30 seconds). When the device is ready to record, the LED briefly turns **green**, then goes dark. The device is now running normally; the LED stays off during operation so it doesn't draw attention on the Underground.

## Checking the device is alive

Double-press the button (two quick taps). The LED flashes twice:

- **Two green flashes** — running normally, all sensors responding
- **Two yellow flashes** — running, but one or more sensors aren't responding (check connections)
- **No flash at all** — the device is off; long-press to turn it on

## Turning the device off

Press and hold the button. After about 2 seconds, the **red LED turns on**. Keep holding or release , the device begins its shutdown:

- If the phone is connected and a data sync is in progress, the device finishes its current data frame before shutting down
- A final status notification is sent to the phone so the app knows how many samples remain unsynced
- The red LED stays on until shutdown is complete
- The LED goes dark and the device enters deep sleep

## LED quick reference

| What you see | What it means |
|---|---|
| Red, solid | Boot in progress, *or* shutdown in progress |
| Green, brief | Boot complete, device is now recording |
| Dark | Normal running operation (device on), or device is off |
| Two green flashes | Health check: all sensors OK |
| Two yellow flashes | Health check: one or more sensors not responding |

## Button quick reference

| Gesture | When device is **off** | When device is **on** |
|---|---|---|
| Single short press | (no effect — device stays asleep) | (no defined action) |
| Double press | (no effect) | Health-check flash |
| Long-press (~2 s) | Turn device on | Turn device off |

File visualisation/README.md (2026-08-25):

# Visualisation & Analysis

Analysis scripts and figures for the first real-world study run with Commuta: **how London Underground line types and platform ventilation designs affect commuters' PM2.5 exposure** (MSc dissertation case study). The Commuta system itself is general-purpose — this folder is where its data was put to work on one specific question.

All scripts read from the reproducible dataset in [`../data/`](../data) (see that folder's README for the raw → clean pipeline) and write figures into [`figures/`](figures).

## Setup

```bash
pip install -r requirements.txt
```

(pandas, matplotlib, openpyxl, jupyter — no scipy needed; correlations are computed with pandas/numpy only.)

## Run order

**Step 0 must run first** — it builds the derived analysis tables every plotting script reads:

```bash
python step0_dataprep.py
```

This reads `data/clean/commuta_clean.csv` (never modified) and `data/analysis/station_regime.csv` (the 5-class platform environment taxonomy), and writes `data/analysis/commuta_analysis.csv` (row-level) and `data/analysis/commuta_stops.csv` (stop-level — the analytical unit).

After that, each plotting script is independent and can be run in any order from the repo root.

## Script → figure map

| Script | Output (in `figures/`) | What it shows |
|---|---|---|
| `perline_boxplot.py` | `fig_perline_boxplot.{pdf,png}` | **Fig 4.1a** — Platform PM2.5 by Underground line: box plots per line (TfL line colours), per-stop medians overlaid, UK DAQI thresholds as background bands |
| `platform_mode.py` | `fig_platform_mode.{pdf,png}` | **Fig 4.1b** — the mechanism figure: platform PM2.5 by platform-environment class, ordered along the enclosure gradient, pooled across lines |
| `perstation.py` | `Jubilee_per_station.{pdf,png}`, `H&C_per_station.{pdf,png}` | Per-station PM2.5 stem profiles for the two lines examined in detail — within-line evidence that platform environment, not line, drives exposure |
| `within_journey.py` | `northern_within_journey.{pdf,png}`, `elizabeth_within_journey.{pdf,png}` | **Fig 4.2** — within-journey PM2.5 time series contrasting a deep tube line (no platform screen doors) with a fully screened modern line |
| `plot_4_3_dwell_vs_pm25.py` | `fig_4_3_dwell_vs_pm25.{pdf,png}` | **Fig 4.3** — platform dwell time vs stop-mean PM2.5, with Spearman correlations (self-contained; rebuilds its own stop table) |
| `dwell_spearman_cell.py` | (console/table output) | The stop-level table and Spearman correlation behind Fig 4.3, as a standalone reproducible cell |

## Other contents

- [`notebooks/analysis.ipynb`](notebooks/analysis.ipynb) — exploratory analysis notebook.
- [`exhibition_data/`](exhibition_data) — a single-journey Excel export prepared for exhibition display.
- `commuta_pm25_co2.{png,svg}` and the `*_busier.*` variants in `figures/` — additional comparison figures.

## Reproducing from scratch

The full chain, starting from untouched raw device exports:

```bash
cd data && python process_data.py     # raw → clean (rule-driven, auditable)
cd ..
python visualisation/step0_dataprep.py       # clean → analysis tables
python visualisation/perline_boxplot.py      # then any figure scripts, any order
```

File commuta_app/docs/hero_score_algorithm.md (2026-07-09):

# Commuta Hero Score

The Home screen's centrepiece — a single number, 0–100 (higher is cleaner), plus a plain-English descriptor. It condenses a live sensor reading into an at-a-glance answer to "how bad is the air right now?".

## The idea

Rather than averaging or weighting pollutants — a choice that would need literature-sourced weights we don't have — Commuta uses **worst-metric-drives-the-score**. Whichever pollutant is furthest into its own pollution scale sets the overall band. This is the same principle behind the UK DAQI and the US EPA AQI: take the max sub-index, not the average.

Each metric's sub-score is aligned with its DAQI band structure so the overall descriptor stays consistent with what any single metric would say in isolation: a metric in its DAQI "Low" band always produces a "Good" contribution, a metric in "Moderate" always produces a "Moderate Pollution" contribution, and so on.

## The formula

For each metric with DAQI band boundaries `vLow`, `vMod`, `vHigh` (upper bounds of the Low, Moderate and High bands respectively), the sub-score is a piecewise-linear map:

```
value ≤ 0        → score = 100
value ≤ vLow     → score = 100 − 25 × (value / vLow)              // 75–100  (Good)
value ≤ vMod     → score = 75  − 25 × (value − vLow) / (vMod − vLow)  // 50–75   (Moderate Pollution)
value ≤ vHigh    → score = 50  − 25 × (value − vMod) / (vHigh − vMod) // 25–50   (High Pollution)
value > vHigh    → score = 25  − 25 × (value − vHigh) / (vHigh − vMod), clamped to [0, 25]  // Severe Pollution
```

The overall Hero Score is the minimum across all available sub-scores, floored to the nearest integer:

```
Hero Score = floor(min across available metrics of sub-score)
```

Flooring rather than rounding matters at band boundaries: a metric that has just crossed into a worse DAQI band should read as the worse-band descriptor. For example, PM2.5 at 53.2 µg/m³ sits 0.2 µg/m³ into the High band and produces a raw sub-score of 49.7. Rounding to 50 would flip the descriptor back to "Moderate Pollution"; flooring to 49 keeps it aligned with the actual DAQI band as "High Pollution".

Descriptor cutoffs land exactly at the band boundaries:

| Score | Descriptor |
|---|---|
| 75–100 | Good |
| 50–74 | Moderate Pollution |
| 25–49 | High Pollution |
| 0–24 | Severe Pollution |

## Band boundaries

| Metric | Low band top | Moderate top | High top | Reference |
|---|---|---|---|---|
| PM2.5 | 35 µg/m³ | 53 µg/m³ | 70 µg/m³ | DEFRA DAQI |
| PM10 | 50 µg/m³ | 75 µg/m³ | 100 µg/m³ | DEFRA DAQI |
| CO₂ | 800 ppm | 1500 ppm | — | Indoor ventilation guidance |
| NOx index | 30 | 150 | 300 | Sensirion SGP41 |
| VOC index | 150 | 250 | 400 | Sensirion SGP41 |

CO₂ has only three DAQI bands (Good ventilation, Adequate, Poor). Its sub-score therefore floors at 25 — CO₂ alone can never push the card into "Severe Pollution".

## Worked examples

All three examples use real device readings.

**Ambient office air.** PM2.5 = 7.6, PM10 = 7.6, CO₂ = 525 ppm, NOx = 1, VOC = 100. Sub-scores work out to 95, 96, 84, 99 and 83 respectively; VOC's 83 is the minimum. Hero: **83, "Good"**, sage green.

**Poor ventilation.** Same PM and SGP41 values, but CO₂ climbs to 1000 ppm — now in the Adequate band. CO₂'s sub-score drops to `75 − 25 × (200 / 700) ≈ 68`, which is now the minimum. Hero: **68, "Moderate Pollution"**, olive-yellow.

**A vape puff.** PM2.5 spikes to 4153 µg/m³ — deep into Very High territory. Its sub-score is `25 − 25 × (4083 / 17)`, which is far below zero and clamps to **0**. Hero: **0, "Severe Pollution"**, deep coral-red.

## Visualising the score

The Home card renders the score on a 20-segment semicircular arc:

- All 20 segments take the score's own colour (one of ten palette entries, one per 10-point range).
- Leftmost `round(score / 5)` segments render at full opacity; the rest at 50%. Score 0 keeps the leftmost segment at full opacity as a "worst end" marker.
- The number and descriptor pill both use a darker shade of the same palette colour, so the whole card speaks one colour language driven purely by the score.

## Excluded from the score

- **PM1** — no official DAQI band exists for it. It's still shown in the metric grid but doesn't participate in scoring.
- **NOx and VOC indices** — dropped from the calculation while the SGP41 is conditioning (roughly the first minute after power-on). The remaining PM and CO₂ metrics still drive the score during that window.

## Why not a weighted sum?

A weighted sum (`a·PM2.5 + b·PM10 + …`) is the obvious alternative but runs into three problems: the metrics have different units (µg/m³, ppm, dimensionless indices), the weights would need commuter-exposure literature that isn't readily available, and one severely elevated pollutant can be masked by clean readings on the others. The worst-metric approach sidesteps all three, and matches how established outdoor AQIs actually work.

Swapping to a weighted-sum formula later is a single-function replacement in [`hero_score_service.dart`](../commuta_app/lib/services/hero_score_service.dart) — the widget doesn't care where the number comes from.

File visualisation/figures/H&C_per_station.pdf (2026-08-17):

## Hammersmith & City — platform PM2.5 by station (route order)

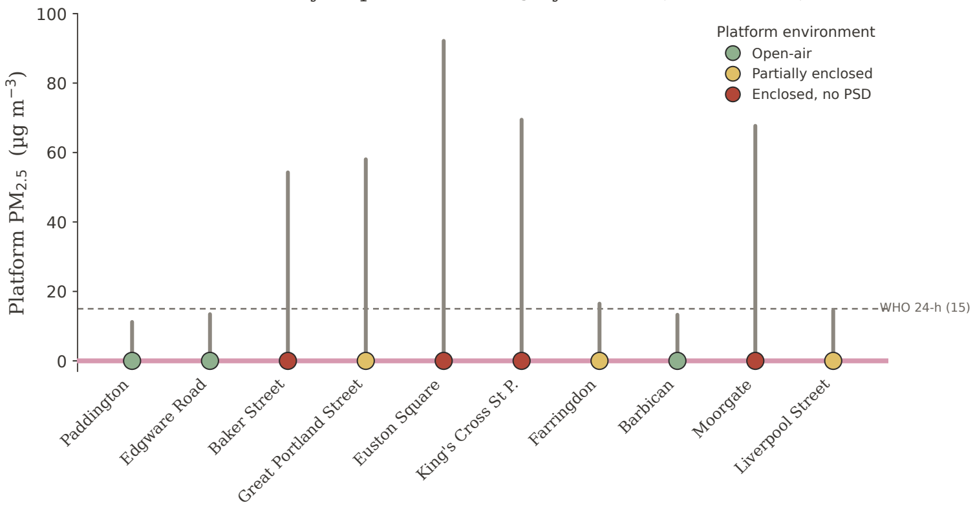
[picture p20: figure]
Paddington; Edgware Road; Baker Street; Great Portland Street Euston Square; King's Cross St P.; Farringdon; Barbican; Moorgate; Liverpool Street; Platfo; WHO 24-h (15); Platform environment Open-air Partially enclosed Enclosed, no PSD

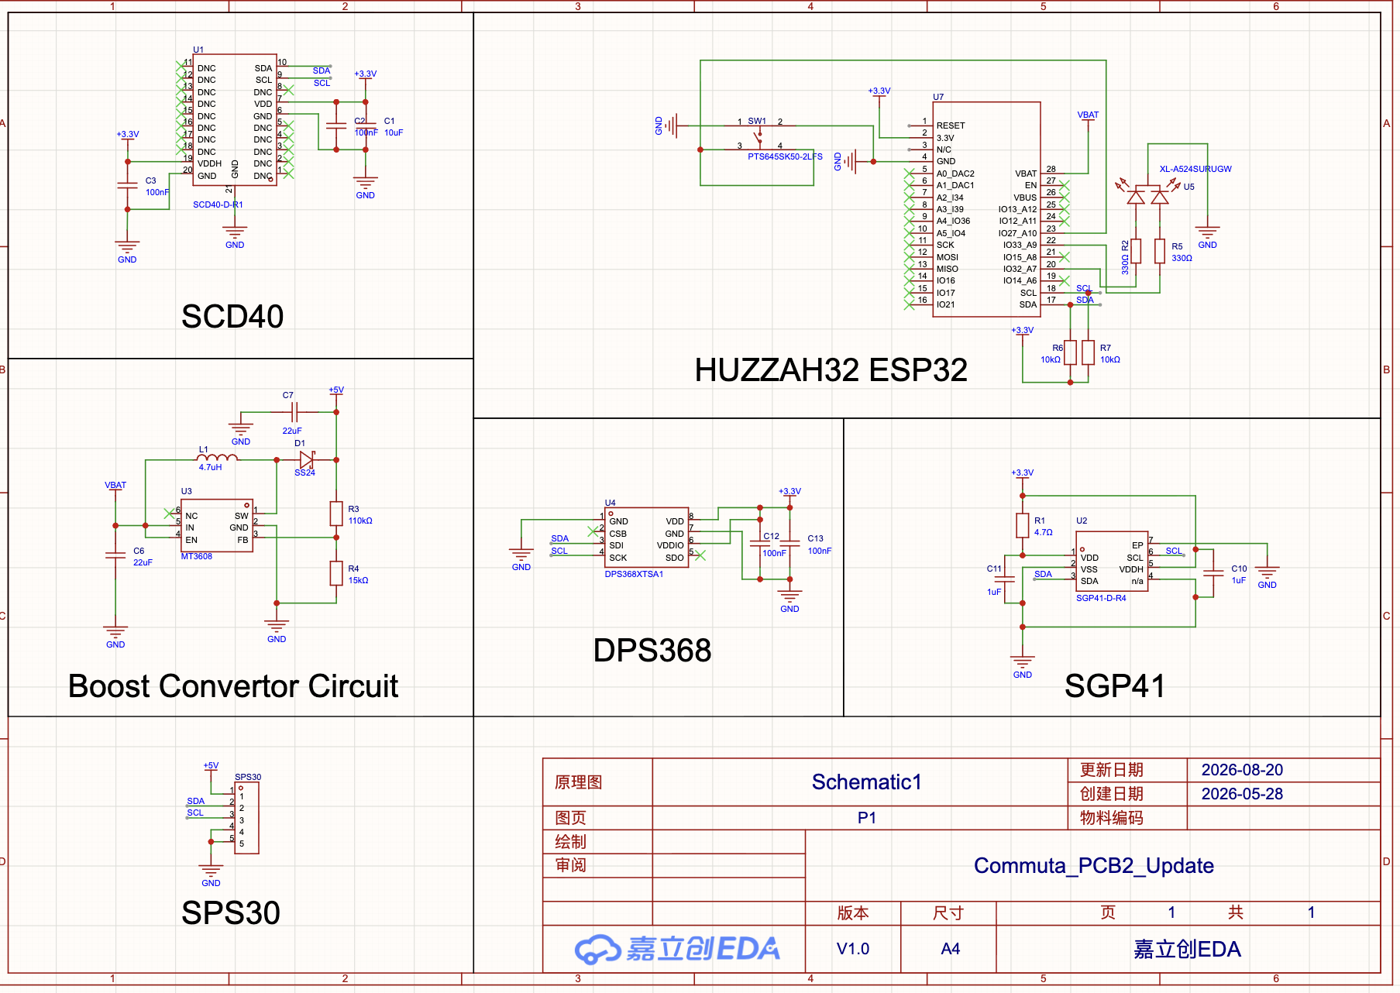
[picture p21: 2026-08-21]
Media/Images/PCB_schematic.png

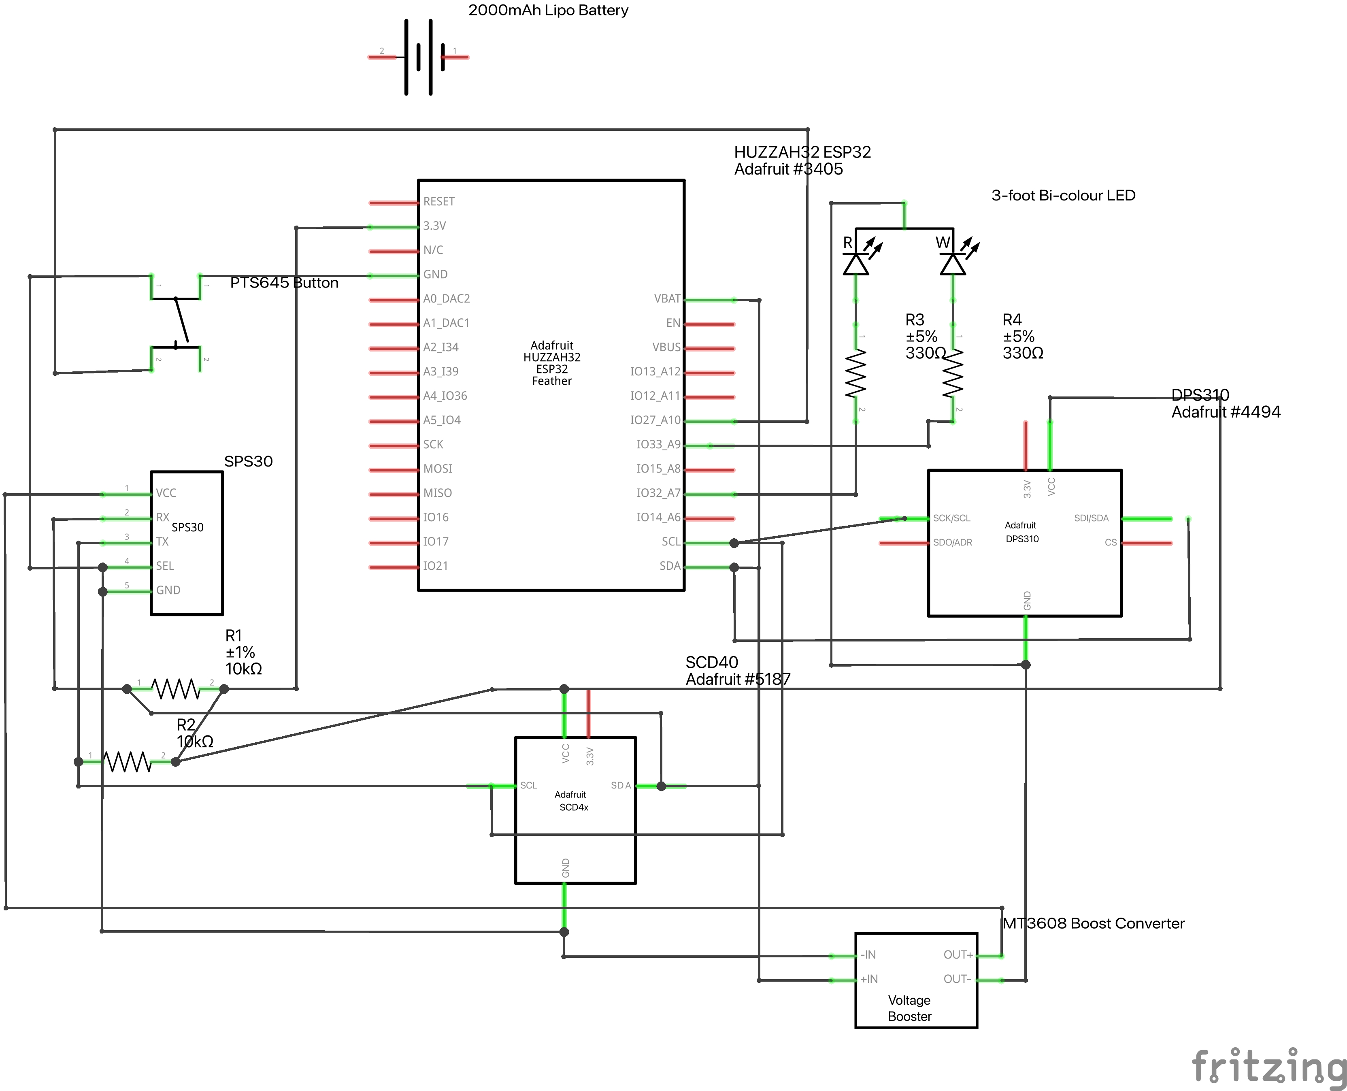
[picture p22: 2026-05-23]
test_SPS30/Schematic.jpg

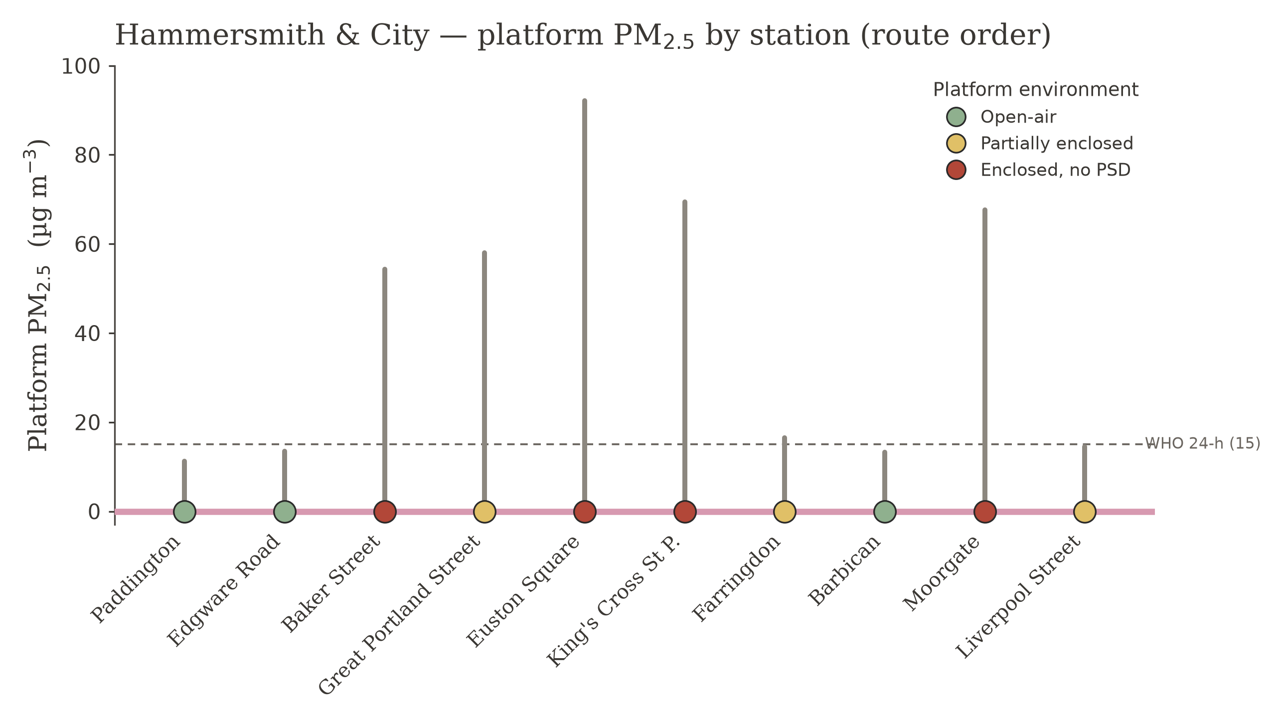
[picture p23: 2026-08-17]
visualisation/figures/H&C_per_station.png

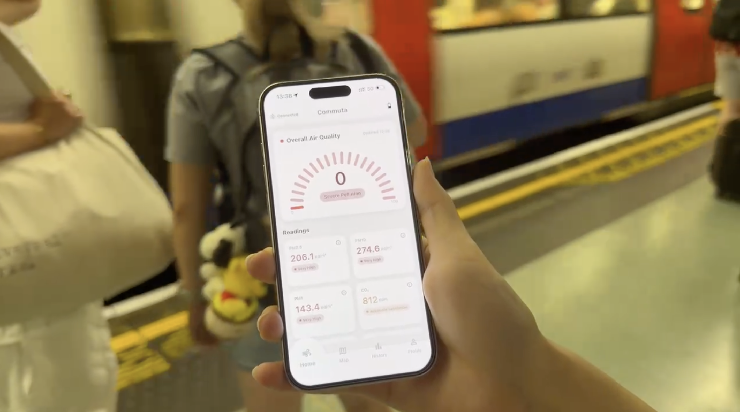
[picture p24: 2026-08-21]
Media/Images/in_use2.png

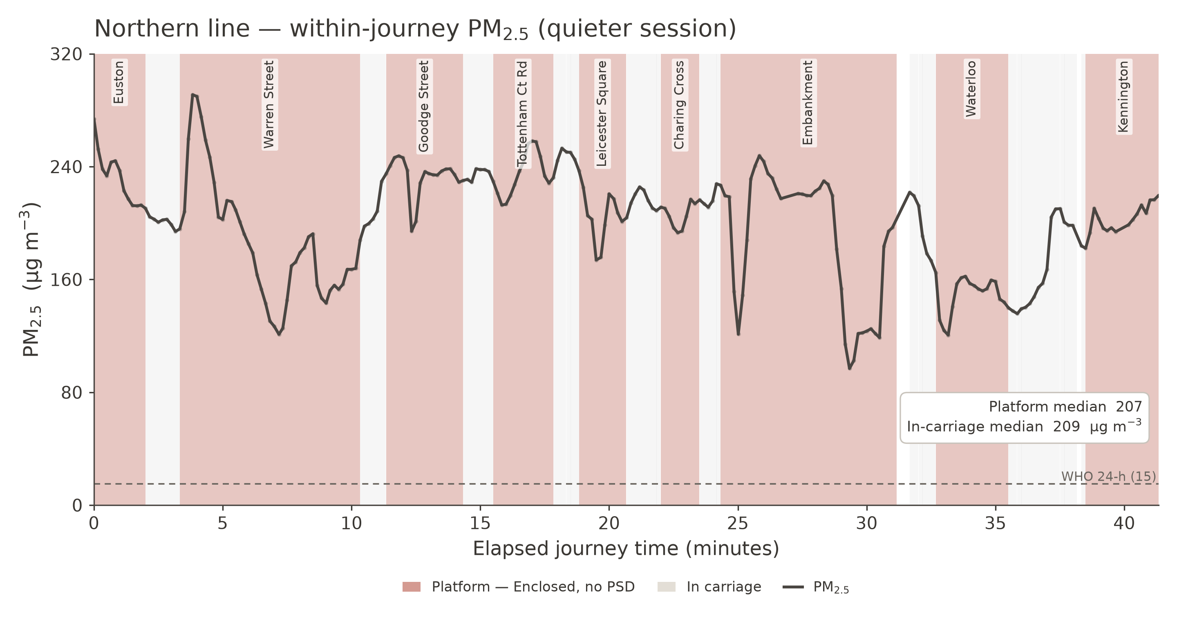
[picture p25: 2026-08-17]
visualisation/figures/northern_within_journey.png

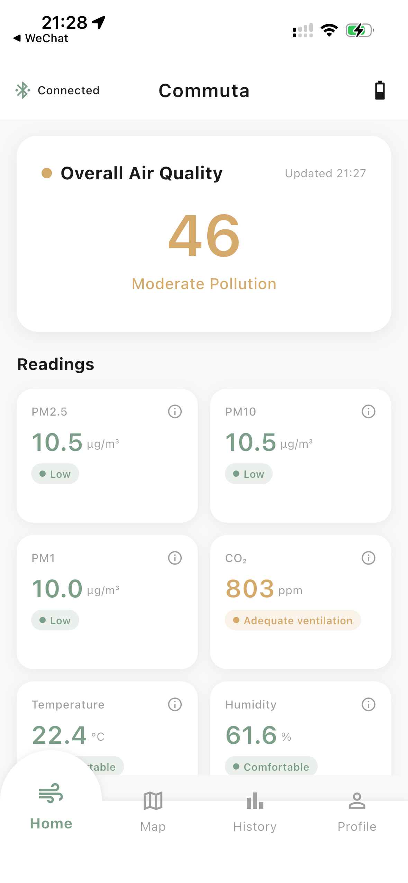
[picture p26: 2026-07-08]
commuta_app/docs/images/herocard_yellow.PNG

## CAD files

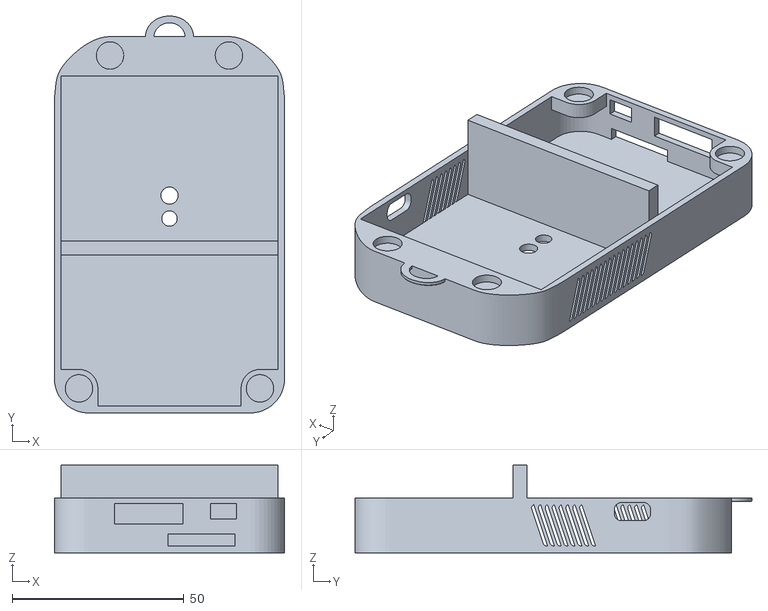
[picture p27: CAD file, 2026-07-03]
enclosure/final_version/FinalVersion_Top.stl
67.0 x 115.5 x 25.5

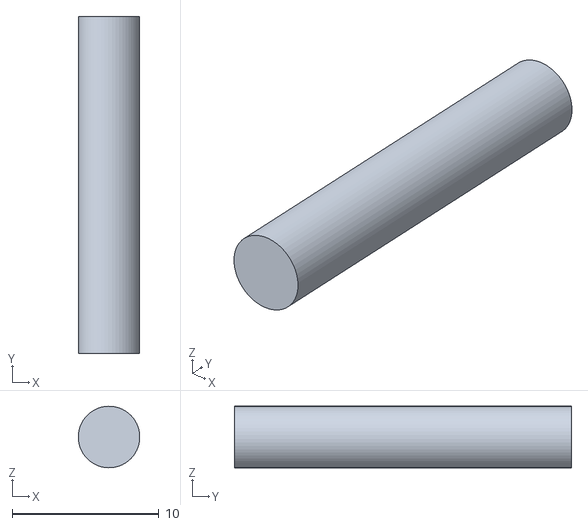
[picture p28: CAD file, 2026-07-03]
enclosure/version9/ButtonCover2.stl
4.20 x 23.0 x 4.20

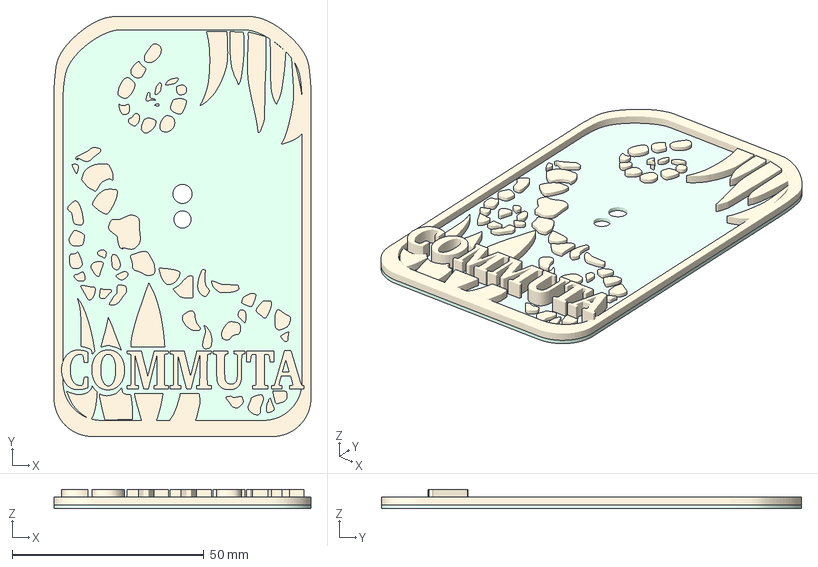
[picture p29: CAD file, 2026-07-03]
enclosure/final_version/FinalVersion_浮雕.3mf
67.0 x 109.5 x 5.00 mm

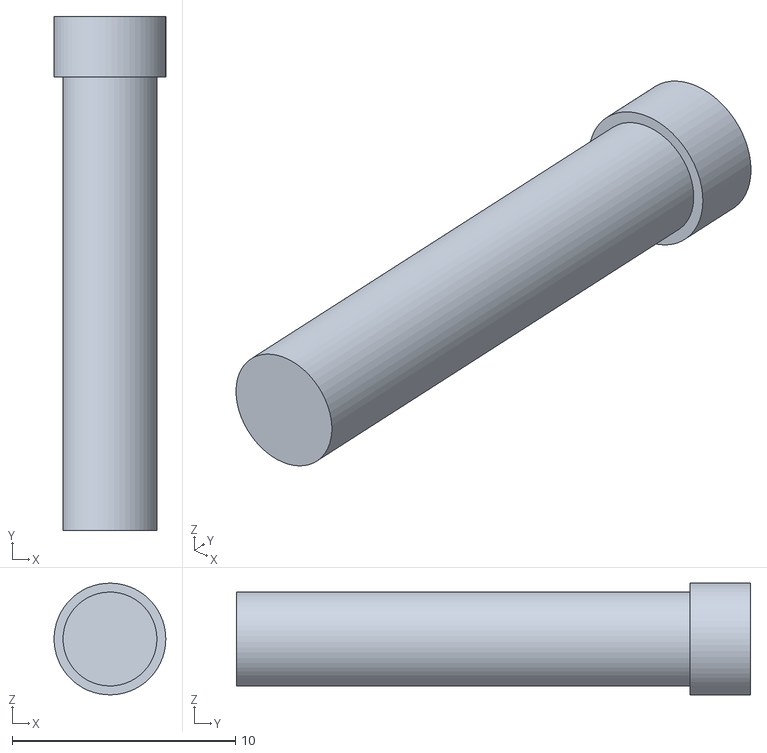
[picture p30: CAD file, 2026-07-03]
enclosure/final_version/ButtonCover3.stl
5.00 x 23.0 x 5.00

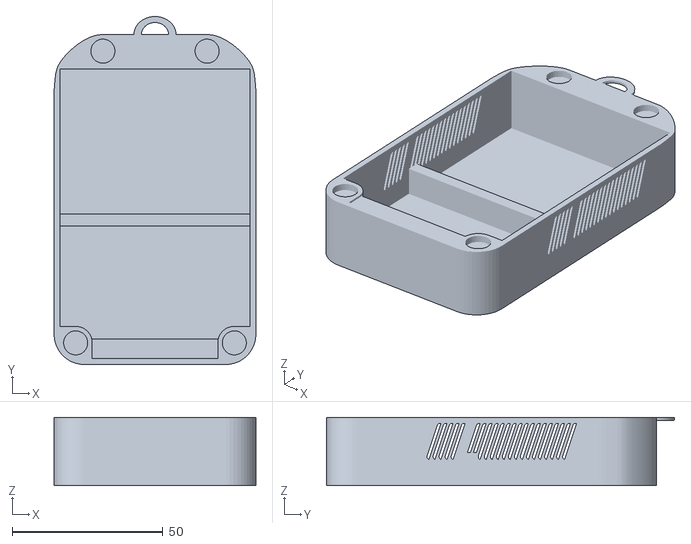
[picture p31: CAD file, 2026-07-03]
enclosure/final_version/FinalVersion_Bottom.stl
67.0 x 115.5 x 22.7

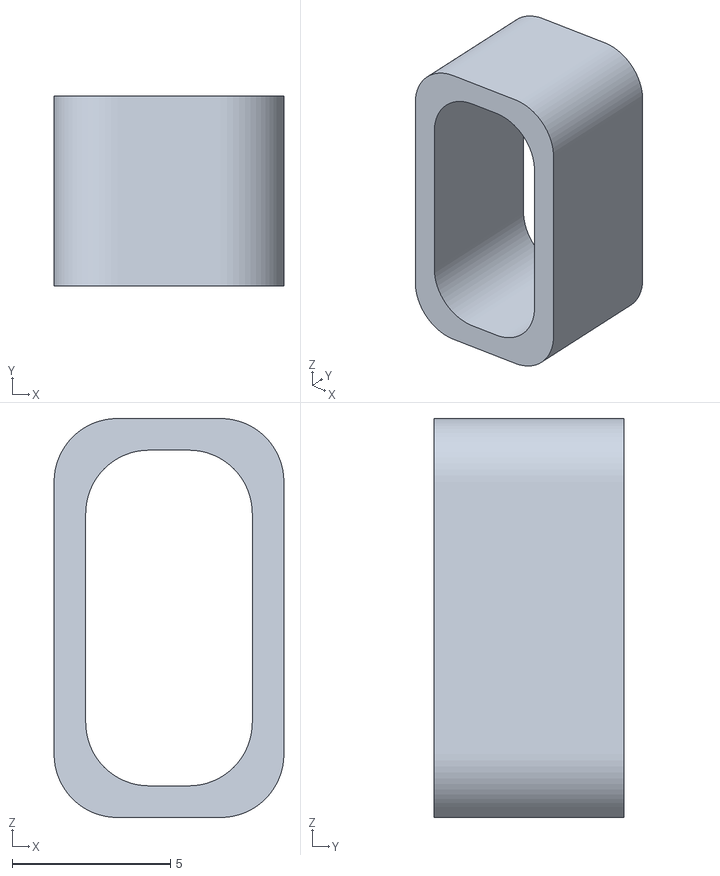
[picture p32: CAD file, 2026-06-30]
enclosure/final_version/TypeC.stl
7.26 x 6.00 x 12.6

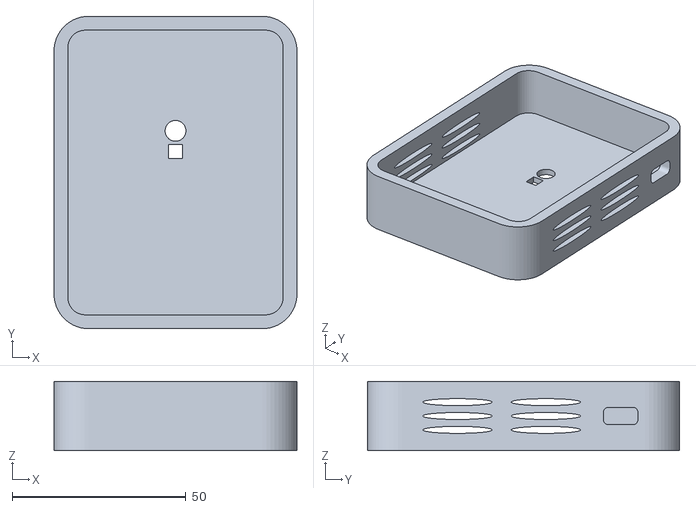
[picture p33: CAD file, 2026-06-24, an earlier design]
enclosure/version1/Commuta_Try1.stl
70.0 x 90.0 x 20.0

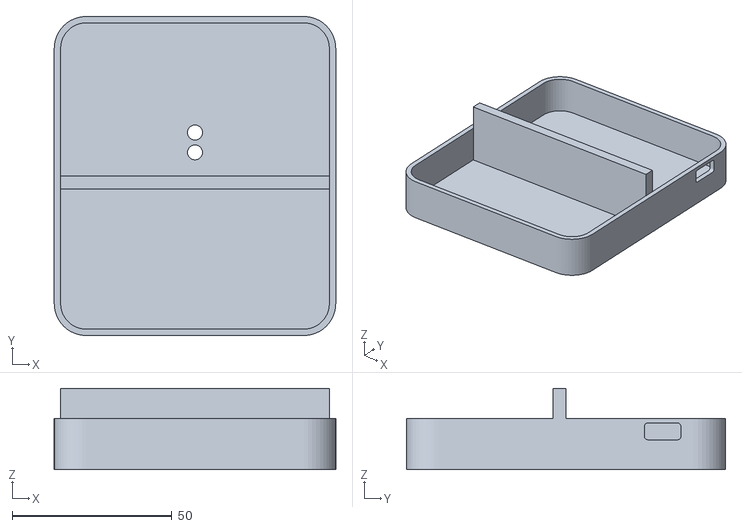
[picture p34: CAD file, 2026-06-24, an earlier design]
enclosure/version2/Annie_Commuta_test2_top.stl
88.3 x 100.0 x 25.5

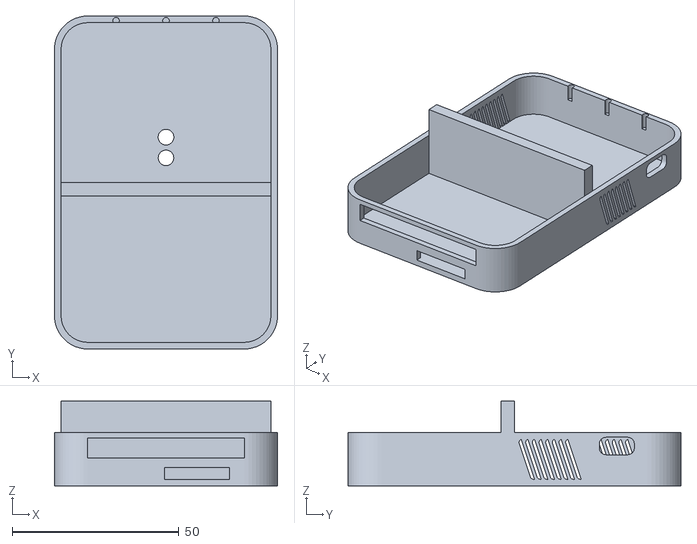
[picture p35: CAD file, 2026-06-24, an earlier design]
enclosure/version3/Commuta_Try3_Top.stl
67.0 x 100.0 x 25.5

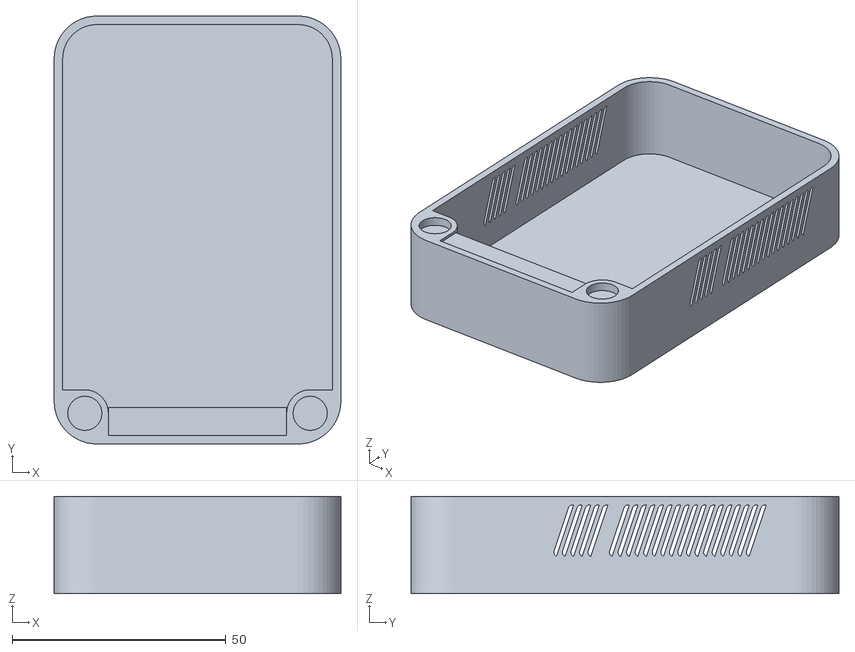
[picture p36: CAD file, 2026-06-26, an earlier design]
enclosure/version5/Commuta_Botton_2Holes.stl
67.0 x 100.0 x 22.7

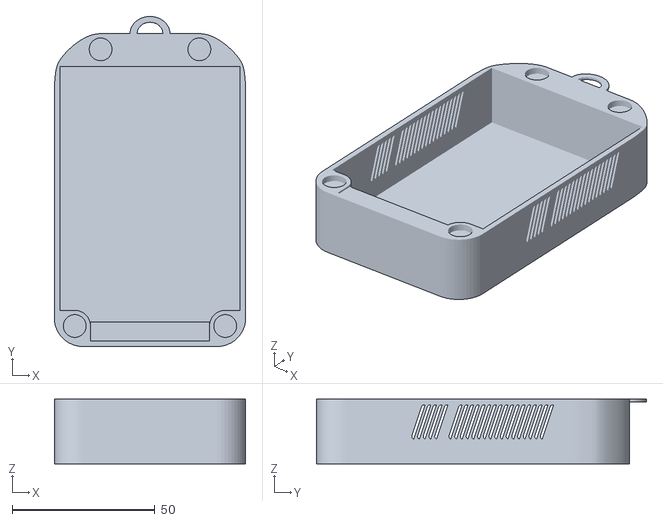
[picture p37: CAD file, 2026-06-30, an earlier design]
enclosure/version7/Commuta_Draft9.stl
67.0 x 115.5 x 22.7

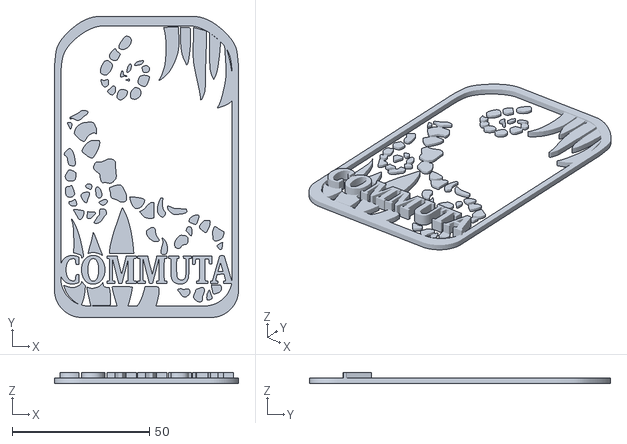
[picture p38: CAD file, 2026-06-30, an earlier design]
enclosure/version8/Commuta_浮雕body1_version8.stl
67.0 x 109.5 x 4.00

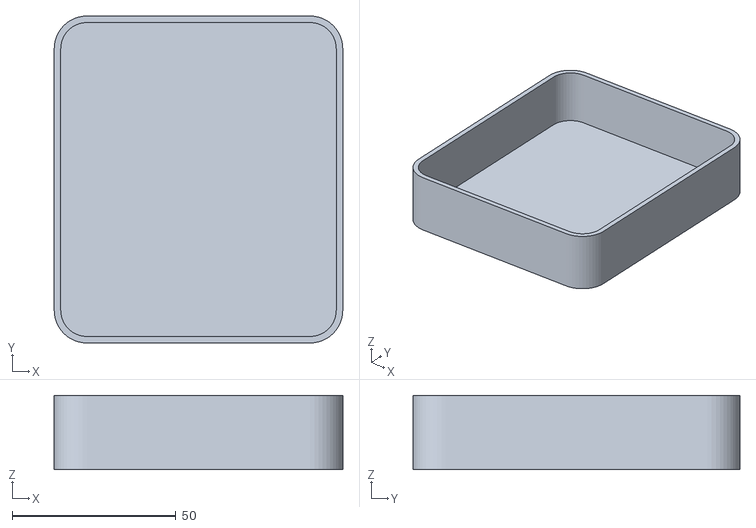
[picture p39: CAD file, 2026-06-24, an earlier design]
enclosure/version2/Annie_Commuta_test2_bottom.stl
88.3 x 100.0 x 22.7

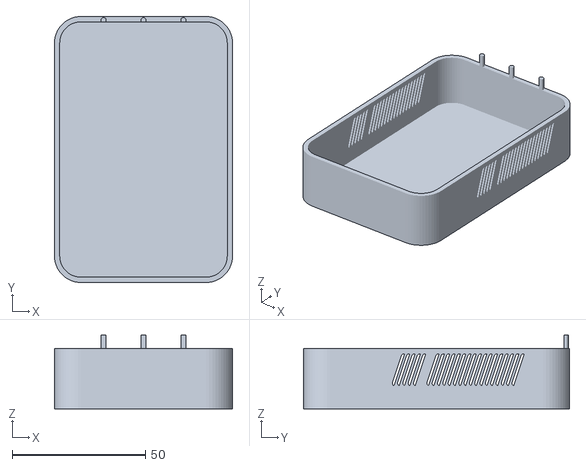
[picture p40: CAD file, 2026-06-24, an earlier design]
enclosure/version3/Commuta_Try3_Bottom.stl
67.0 x 100.0 x 27.7

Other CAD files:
enclosure/version4/Commuta_top_two_holes.stl
enclosure/version6/Version6Top.stl
enclosure/version4/Commuta_Bottom_Two_holes.stl
enclosure/version5/Commuta_Top_2Holes.stl
enclosure/version6/Version6Bottom.stl
enclosure/version6/Version6浮雕.stl
enclosure/version7/Commuta_Draft8.stl
enclosure/version7/浮雕2bodies.3mf
enclosure/version8/Commuta_Bottom_version8.stl
enclosure/version8/Commuta_Top_version8.stl
enclosure/version8/Commuta_浮雕2bodies_version8.3mf
enclosure/version8/Commuta_浮雕body2_version8.stl

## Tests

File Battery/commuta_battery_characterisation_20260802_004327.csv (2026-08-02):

boot_epoch | sequence_number | timestamp | vbat_mv | dps368_temp_c | source_flag
3090751706 | 95 | 2026-08-01T00:17:51.000+01:00 | 3860 | 30.82825469970703 | buffered
3090751706 | 96 | 2026-08-01T00:18:01.000+01:00 | 3858 | 30.866256713867188 | buffered
3090751706 | 97 | 2026-08-01T00:18:11.000+01:00 | 3931 | 30.263427734375 | live
3090751706 | 98 | 2026-08-01T00:18:21.000+01:00 | 3923 | 30.303970336914062 | live
3090751706 | 99 | 2026-08-01T00:18:31.000+01:00 | 3904 | 30.330909729003906 | live
3090751706 | 100 | 2026-08-01T00:18:41.000+01:00 | 3920 | 30.361251831054688 | live
3090751706 | 101 | 2026-08-01T00:18:51.000+01:00 | 3915 | 30.443199157714844 | live
3090751706 | 102 | 2026-08-01T00:19:01.000+01:00 | 3902 | 30.48175811767578 | live
3090751706 | 103 | 2026-08-01T00:19:11.000+01:00 | 3897 | 30.534500122070312 | live
3090751706 | 104 | 2026-08-01T00:19:21.000+01:00 | 3921 | 30.590072631835938 | live
3090751706 | 105 | 2026-08-01T00:19:31.000+01:00 | 3912 | 30.64905548095703 | live
3090751706 | 106 | 2026-08-01T00:19:41.000+01:00 | 3925 | 30.698394775390625 | live
3090751706 | 107 | 2026-08-01T00:19:51.000+01:00 | 3928 | 30.733551025390625 | live
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

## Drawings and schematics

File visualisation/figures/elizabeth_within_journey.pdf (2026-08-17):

# Elizabeth line — within-journey PM2.5 (quieter session)

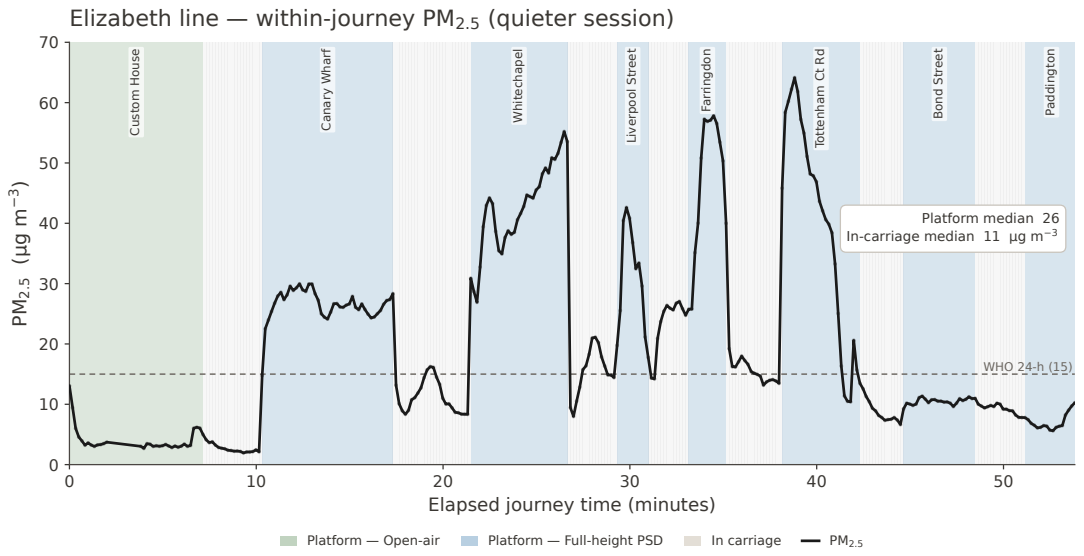
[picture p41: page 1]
WHO 24-h (15); Platform — Open-air; Platform — Full-height PSD; In carriage; Custom House; Canary Wharf; Whitechapel; Liverpool Street; Farringdon; Bond Street; Paddington; Platform median 26; In-carriage median

Tottenham Ct Rd

Elapsed journey time (minutes)

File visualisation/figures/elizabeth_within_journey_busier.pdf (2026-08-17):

# Elizabeth line — within-journey PM2.5 (busier session)

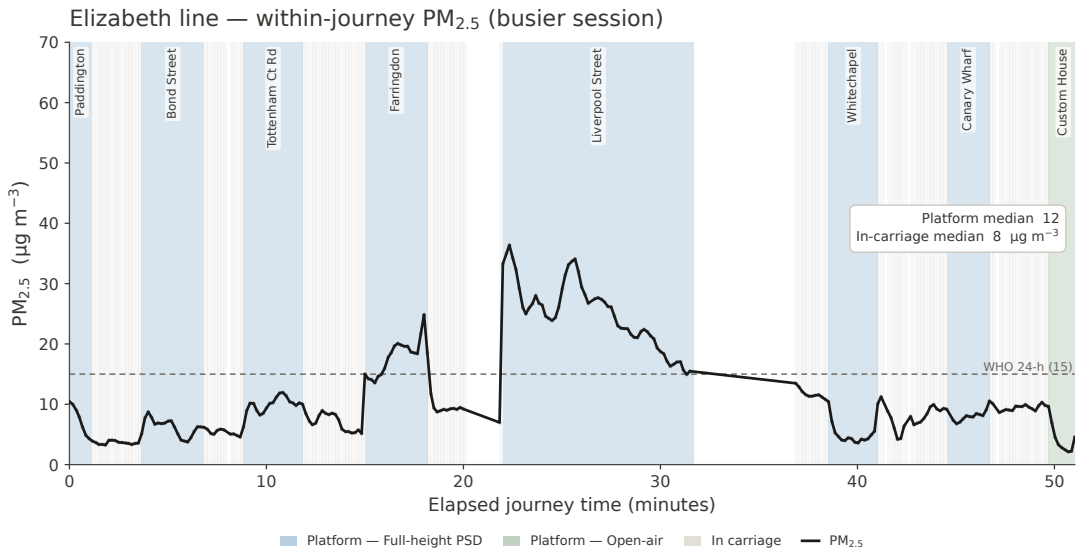
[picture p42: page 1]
WHO 24-h (15); Platform — Full-height PSD; Platform — Open-air; In carriage; Paddington; Bond Street; Farringdon; Liverpool Street; Whitechapel; Canary Wharf; Custom House; Platform median; In-carriage median

Tottenham Ct Rd

Elapsed journey time (minutes)

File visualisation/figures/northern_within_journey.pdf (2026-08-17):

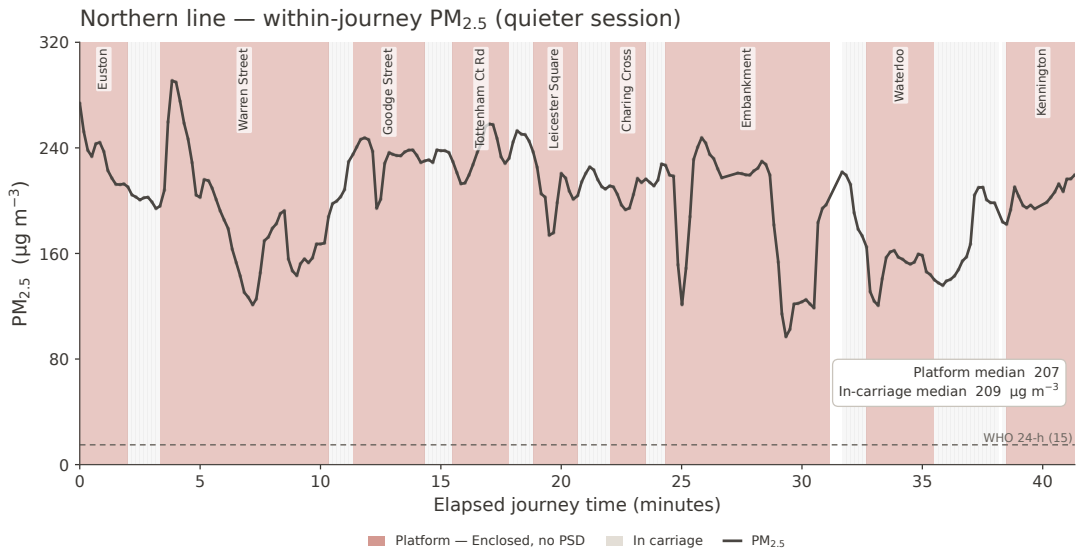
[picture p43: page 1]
WHO 24-h (15); Platform — Enclosed, no PSD; In carriage; Euston; Warren Street; Goodge Street; Leicester Square; Charing Cross; Embankment; Waterloo; Kennington; Platform median 207; In-carriage median

Northern line — within-journey PM2.5 (quieter session)

Tottenham Ct Rd

Elapsed journey time (minutes)

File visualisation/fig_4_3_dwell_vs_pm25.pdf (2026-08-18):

100

200

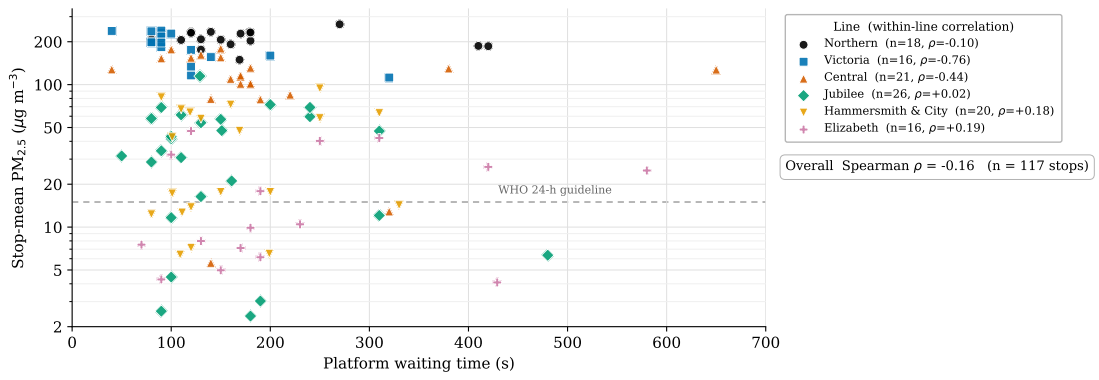
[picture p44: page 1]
WHO 24-h guideline; Line (within-line correlation) N

Stop-mean PM2.5 (μg m−3)

Platform waiting time (s)

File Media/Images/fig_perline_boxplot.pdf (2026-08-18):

250

300

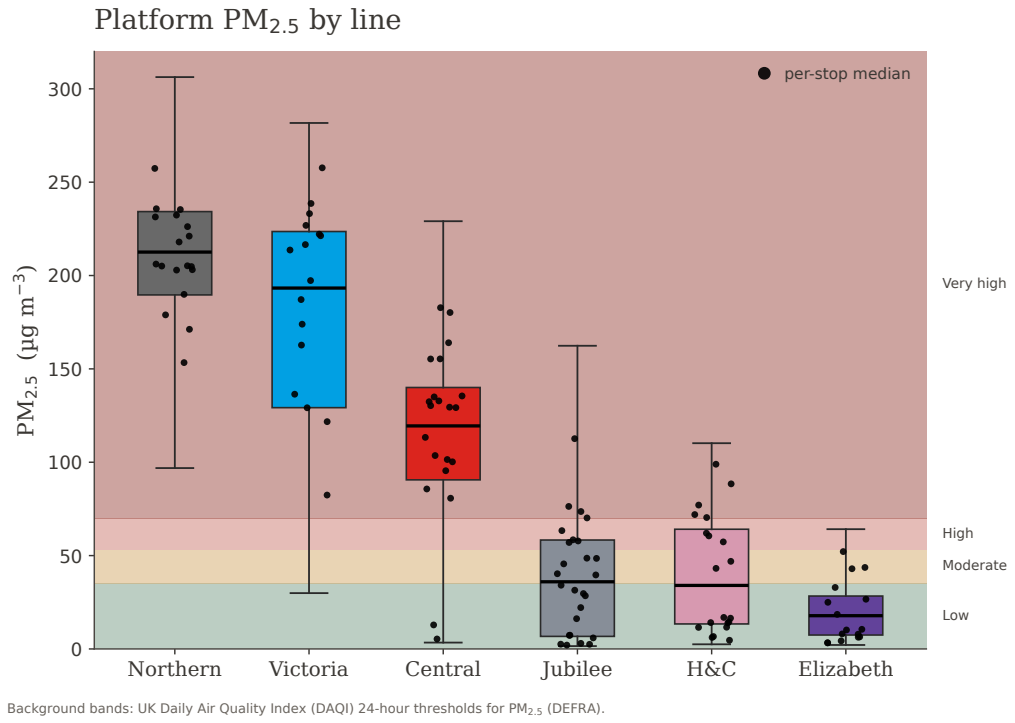
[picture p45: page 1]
Northern; Victoria; Central; Jubilee; Elizabeth; Low; Moderate; High; Very high

Platform PM2.5 by line

per-stop median

Background bands: UK Daily Air Quality Index (DAQI) 24-hour thresholds for PM2.5 (DEFRA).

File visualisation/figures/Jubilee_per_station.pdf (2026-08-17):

## Jubilee — platform PM2.5 by station (route order)

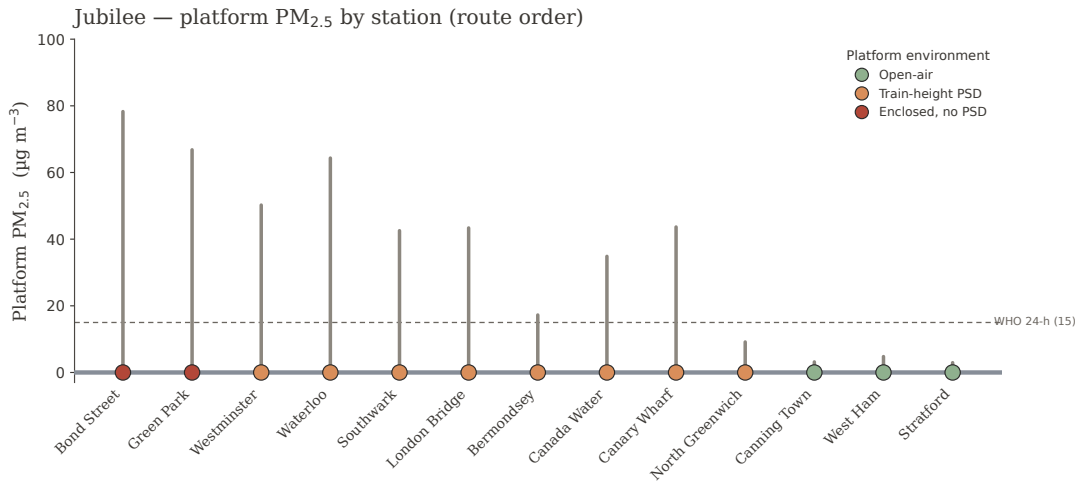
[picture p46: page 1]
Bond Street; Green Park Westminster; Waterloo; Southwark London Bridge; Bermondsey Canada Water; Canary Wharf; North Greenwich Canning Town; West Ham; Stratford; Platfo; WHO 24-h (15)

Platform environment
Open-air
Train-height PSD
Enclosed, no PSD

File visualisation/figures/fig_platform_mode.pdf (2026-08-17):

## Platform PM2.5 by platform environment (all lines pooled)

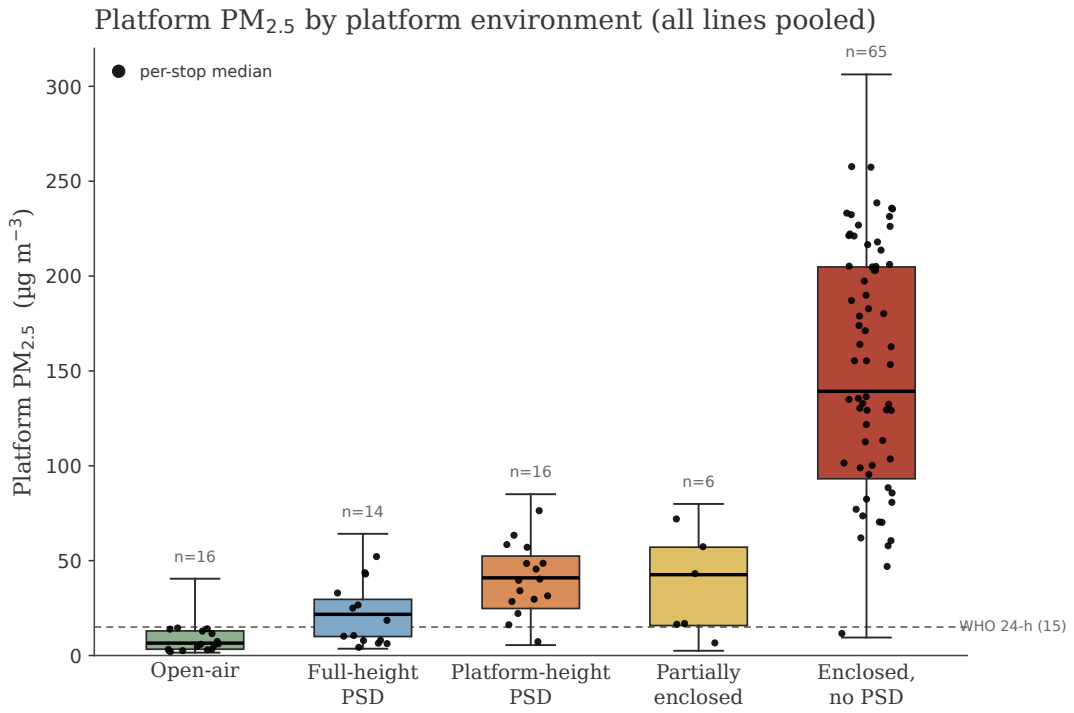
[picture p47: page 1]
Open-air; Full-height; PSD; Platform-height PSD; Partially enclosed; Enclosed, no PSD; Platfo; WHO 24-h (15)

per-stop median

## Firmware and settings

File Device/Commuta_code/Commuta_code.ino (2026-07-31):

// Commuta - A Portable Air Quality Monitor

// Raw data for the 2nd version PCB

// Microcontroller Adafruit HUZZAH32 (ESP32)
// Sensors: SPS30 (PM), SCD40 (CO2/Tem/Hum), DPS368 (air pressure), SGP41 (VOC/NOx)
// Others: button, red & green bio-colour LED

// I2C: SDA = GPIO23, SCL = GPIO22

#include <Wire.h>
#include <Adafruit_DPS310.h>
#include <SensirionI2cScd4x.h>
#include <SensirionI2cSps30.h>
#include <SensirionI2CSgp41.h>
#include <VOCGasIndexAlgorithm.h>
#include <NOxGasIndexAlgorithm.h>

#include <esp_sleep.h>
#include <driver/rtc_io.h>
#include <esp_random.h>   // esp_random() hardware RNG for boot_epoch
#include <Preferences.h>  // NVS-backed persistence for boot_epoch

#include "ble.h"
#include "storage.h"
#include "button.h"

// ---------- pin map ----------
#define PIN_BUTTON 27
#define PIN_LED_RED 32
#define PIN_LED_GREEN 33
#define PIN_BATTERY_ADC 35  // internal, divider on board, reads Vbat/2

// ---------- sensor objects ----------
SensirionI2cSps30 sps30;
Adafruit_DPS310 dps;
SensirionI2cScd4x scd4x;
SensirionI2CSgp41 sgp41;
VOCGasIndexAlgorithm vocAlgo;
NOxGasIndexAlgorithm noxAlgo;

// ---------- Expected I2C devices ----------
// Used by the on-demand health probe (see probeAllSensorsHealthy). Order
// is informational only; the probe checks all of them on every call.
struct SensorInfo {
  uint8_t addr;
  const char* name;
};
static const SensorInfo kSensors[] = {
  { 0x59, "SGP41" },
  { 0x62, "SCD40" },
  { 0x69, "SPS30" },
  { 0x77, "DPS368" },
};
static const size_t kNumSensors = sizeof(kSensors) / sizeof(kSensors[0]);

// ---------- SGP41 timing & state ----------
// Default compensation: 50 %RH, 25 degC, in SGP41 tick format
const uint16_t SGP41_DEFAULT_RH = 0x8000;             // 50  * 65535 / 100
const uint16_t SGP41_DEFAULT_T = 0x6666;              // (25 + 45) * 65535 / 175
const unsigned long SGP41_CONDITIONING_MS = 10000;    // 10 s NOx hotplate warm-up
const unsigned long SGP41_SAMPLE_INTERVAL_MS = 1000;  // 1 Hz cadence for gas index algorithm

unsigned long sgp41StartMs = 0;
unsigned long lastSgp41Ms = 0;
uint16_t srawVoc = 0;
uint16_t srawNox = 0;
int32_t vocIndex = 0;
int32_t noxIndex = 0;

// ---------- Latest sensor readings (used for both serial print and BLE) ----------
// These persist across loop iterations so that, if a single read fails, the
// BLE packet still carries the most recent valid value rather than zero.
float latestPm1 = 0.0f, latestPm25 = 0.0f, latestPm10 = 0.0f;
uint16_t latestCo2 = 0;
float latestT = 25.0f;
float latestRh = 50.0f;
float latestPressure = 0.0f;
float latestDps368Temp = 25.0f;  // DPS368 ambient temp; reported over BLE (SCD40 temp still logged for SGP41 comp)
bool haveScdReading = false;

// ---------- BLE sample state ----------
uint32_t sampleSequence = 0;  // increments every BLE sample; restored from storage on boot

// ---------- Boot epoch (sample dedup) ----------
// A random 32-bit ID generated once per firmware install and persisted in
// NVS. Stamped onto every sample so the app dedupes on (boot_epoch,
// sequence). Survives ordinary reboots and "Disabled" sketch uploads; only a
// full flash erase (which wipes NVS) forces a new one - which is exactly when
// we WANT a new epoch, because the sample sequence also resets to 0 then, so
// (new_epoch, 0..) can never collide with previously-synced (old_epoch, N).
Preferences g_prefs;
uint32_t bootEpoch = 0;

// ---------- SCD40 pressure compensation (fed from DPS368) ----------
// The SCD40 uses ambient pressure in its internal CO2 physics path, so this
// correction belongs in firmware (post-hoc correction would be lossy). We
// push the latest DPS368 pressure to the SCD40 at least every 30 s, or sooner
// whenever it moves more than 5 hPa (e.g. train pressure transients).
unsigned long lastPressureCompMs = 0;
float lastPressureCompHpa = 0.0f;
const unsigned long PRESSURE_COMP_INTERVAL_MS = 30000;
const float PRESSURE_COMP_DELTA_HPA = 5.0f;

// ---------- print / sample cadence ----------
unsigned long lastPrint = 0;
const unsigned long PRINT_INTERVAL_MS = 10000;  // also the BLE sample interval

// ---------- LED control via explicit LEDC channels ----------
// Each LED pin gets its OWN PWM channel via ledcAttach(). This avoids the
// auto-channel-assignment behaviour in analogWrite() that caused yellow to
// fail on the bench (only green visible when both pins were PWMed at once).
//
// API note: ledcAttach(pin, freq, res) is the ESP32 Arduino core 3.x form.
// If your installed core is 2.x, this won't compile and we'll swap to the
// older ledcSetup + ledcAttachPin pair.
#define LED_PWM_FREQ 5000
#define LED_PWM_RESOLUTION 8  // 0..255 duty
#define LED_DIM_DUTY 16       // ~6% brightness, dim enough for the Underground

static void ledSetup() {
  ledcAttach(PIN_LED_RED, LED_PWM_FREQ, LED_PWM_RESOLUTION);
  ledcAttach(PIN_LED_GREEN, LED_PWM_FREQ, LED_PWM_RESOLUTION);
  ledcWrite(PIN_LED_RED, 0);
  ledcWrite(PIN_LED_GREEN, 0);
}
static void ledOff() {
  ledcWrite(PIN_LED_RED, 0);
  ledcWrite(PIN_LED_GREEN, 0);
}
static void ledRed() {
  ledcWrite(PIN_LED_RED, LED_DIM_DUTY);
  ledcWrite(PIN_LED_GREEN, 0);
}
static void ledGreen() {
  ledcWrite(PIN_LED_RED, 0);
  ledcWrite(PIN_LED_GREEN, LED_DIM_DUTY);
}
static void ledYellow() {
  // Bi-colour LED has a much brighter green die than red at equal duty.
  // Bench sweep landed on (red=200, green=16) as the duty pair that the
  // eye perceives as yellow. If the LED part is ever swapped, re-run the
  // diagnostic sweep — the ratio is part-specific.
  ledcWrite(PIN_LED_RED, 200);
  ledcWrite(PIN_LED_GREEN, LED_DIM_DUTY);
}

// ---------- I2C bus probe ----------
// Direct address-ACK test. Returns true iff a device at `addr` acknowledged
// its address on the bus. This is more reliable than calling into the
// sensor-specific drivers, which may swallow NACK errors and return 0.
static bool i2cProbe(uint8_t addr) {
  Wire.beginTransmission(addr);
  // endTransmission returns:
  //   0 = success (slave ACKed address)
  //   1 = data too long for buffer
  //   2 = NACK on address transmit (device absent / unreachable)
  //   3 = NACK on data transmit
  //   4 = other error
  return Wire.endTransmission() == 0;
}

// Probes all four expected sensors RIGHT NOW. Returns true iff every one
// of them ACKs. Used both at boot (for accurate serial logging) and from
// the double-press handler (live health check for the LED colour).
static bool probeAllSensorsHealthy() {
  bool allOk = true;
  for (size_t i = 0; i < kNumSensors; i++) {
    bool ok = i2cProbe(kSensors[i].addr);
    if (!ok) {
      Serial.printf("Probe: %s @ 0x%02X NOT present\n",
                    kSensors[i].name, kSensors[i].addr);
      allOk = false;
    } else {
      Serial.printf("Probe: %s @ 0x%02X present\n",
                    kSensors[i].name, kSensors[i].addr);
    }
  }
  return allOk;
}

// ---------- helpers ----------
uint16_t humidityToTicks(float rh) {
  if (rh < 0) rh = 0;
  if (rh > 100) rh = 100;
  return (uint16_t)((rh * 65535.0f) / 100.0f);
}
uint16_t temperatureToTicks(float t) {
  if (t < -45) t = -45;
  if (t > 130) t = 130;
  return (uint16_t)(((t + 45.0f) * 65535.0f) / 175.0f);
}

// Raw battery voltage from GPIO35 (internal Vbat/2 divider on the HUZZAH32).
// We now send this raw value over BLE (vbat_mv) and let the app derive SOC
// from an empirically-calibrated OCV table (Phases 4-5). Deliberately no
// smoothing or percentage mapping here: keeping the wire value raw makes the
// dataset reproducible and lets the SOC algorithm be revised without a
// re-flash. Caveat: the 3.3 V reference is nominal and the ESP32 ADC is
// non-linear, so this is an ADC-derived estimate rather than a lab-grade
// voltage. That's fine - the app's OCV table is built against exactly this
// function's output, so any consistent scaling error is absorbed by the
// calibration. (If true absolute mV is ever needed, swap in esp_adc_cal.)
uint16_t readBatteryMillivolts() {
  int raw = analogRead(PIN_BATTERY_ADC);
  float vbat = (raw / 4095.0f) * 3.3f * 2.0f;  // *2 undoes the on-board /2 divider
  uint16_t mv = (uint16_t)(vbat * 1000.0f + 0.5f);
  Serial.printf("Battery: raw=%d vbat=%.3fV (%u mV)\n", raw, vbat, mv);
  return mv;
}

// Coarse percentage for the Status characteristic ONLY - a rough live UI
// indicator, never research data. Real SOC is computed app-side from vbat_mv.
// Kept so the Status wire format (and the app's Status parser) stays unchanged.
static uint8_t coarseBatteryPct(uint16_t mv) {
  long pct = ((long)mv - 3300) * 100 / (4200 - 3300);
  if (pct < 0) pct = 0;
  if (pct > 100) pct = 100;
  return (uint8_t)pct;
}

// Generate-or-restore the per-install boot epoch. Called once early in setup.
static void initBootEpoch() {
  g_prefs.begin("commuta", false);  // namespace "commuta", read-write
  bootEpoch = g_prefs.getUInt("epoch", 0);
  if (bootEpoch == 0) {
    bootEpoch = esp_random();       // 32-bit hardware RNG
    if (bootEpoch == 0) bootEpoch = 1;  // 0 is our "unset" sentinel; avoid it
    g_prefs.putUInt("epoch", bootEpoch);
    Serial.printf("boot_epoch: generated new %08X\n", (unsigned)bootEpoch);
  } else {
    Serial.printf("boot_epoch: restored %08X\n", (unsigned)bootEpoch);
  }
  g_prefs.end();
}

void sampleSgp41() {
  bool conditioning = (millis() - sgp41StartMs) < SGP41_CONDITIONING_MS;
  uint16_t err;
  if (conditioning) {
    err = sgp41.executeConditioning(SGP41_DEFAULT_RH, SGP41_DEFAULT_T, srawVoc);
    srawNox = 0;
  } else {
    uint16_t rhT = haveScdReading ? humidityToTicks(latestRh) : SGP41_DEFAULT_RH;
    uint16_t tT = haveScdReading ? temperatureToTicks(latestT) : SGP41_DEFAULT_T;
    err = sgp41.measureRawSignals(rhT, tT, srawVoc, srawNox);
  }
  if (!err) {
    vocIndex = vocAlgo.process((int32_t)srawVoc);
    if (!conditioning) noxIndex = noxAlgo.process((int32_t)srawNox);
  }
}

// ---------- Deep-sleep entry helpers ----------
// Configure GPIO27 for wake and enter deep sleep. Never returns.
static void enterDeepSleep() {
  Serial.flush();
  // GPIO27 pull-up needs to survive deep sleep; the regular IO_MUX pull-up
  // does not, so re-enable via the RTC GPIO API.
  rtc_gpio_pullup_en((gpio_num_t)PIN_BUTTON);
  rtc_gpio_pulldown_dis((gpio_num_t)PIN_BUTTON);
  esp_sleep_enable_ext0_wakeup((gpio_num_t)PIN_BUTTON, 0);  // wake when LOW
  esp_deep_sleep_start();
  // unreachable
}

// Called from setup() when the wakeup cause is EXT0. Polls GPIO27 until
// either the long-press threshold is reached (returns true and lights the
// red LED) or the user releases early (returns false).
static bool validateWakePress() {
  Serial.println("Wake: validating long-press from sleep");
  uint32_t startMs = millis();
  while (digitalRead(PIN_BUTTON) == LOW) {
    if (millis() - startMs >= COMMUTA_BTN_LONG_PRESS_MS) {
      Serial.println("Wake: long-press confirmed");
      ledRed();
      // Wait for the user to release before we move on, so the running-
      // mode button manager starts in a clean IDLE state.
      while (digitalRead(PIN_BUTTON) == LOW) delay(10);
      delay(COMMUTA_BTN_DEBOUNCE_MS);
      return true;
    }
    delay(5);
  }
  Serial.println("Wake: released before threshold; back to sleep");
  return false;
}

// ---------- Button callbacks ----------
// Threshold crossed: user has held long enough, light red as the "you can
// let go" cue. Runs immediately before the long-press handler.
static void onBtnLongPressThreshold() {
  ledRed();
}

// Double-press: probe all sensors RIGHT NOW and flash twice. Green if every
// expected I2C address ACKs; yellow if any sensor is unreachable. ~600 ms
// total LED time; the brief block in the main loop is well within SGP41's
// tolerance for a missed sample.
static void onBtnDoublePress() {
  bool healthy = probeAllSensorsHealthy();
  Serial.printf("Button: double-press (healthy=%d)\n", (int)healthy);
  for (int i = 0; i < 2; i++) {
    if (healthy) ledGreen();
    else ledYellow();
    delay(150);
    ledOff();
    if (i == 0) delay(150);
  }
}

// Long-press during normal operation: graceful shutdown into deep sleep.
// Never returns (deep sleep ends with esp_deep_sleep_start()).
static void onBtnLongPress() {
  Serial.println("Button: long-press -> shutdown");

  // Per design: finish one more sync frame if mid-stream, then proceed.
  // The phone uses the SHUTTING_DOWN flag (sent below) to finalise its
  // sync state regardless of whether we sent an explicit EOS.
  if (commutaBleIsSyncActive()) {
    Serial.println("Shutdown: sending one more sync frame");
    commutaBleServiceSync();
    delay(50);  // let the radio actually transmit
  }

  // Final Status notification: SHUTTING_DOWN flag + current buffer range
  // so the phone can compute and display the unsynced count.
  uint32_t oldestSeq, newestSeq, bufferedCount;
  commutaStorageGetRange(oldestSeq, newestSeq, bufferedCount);

  CommutaStatus status = {};
  status.uptime_seconds = millis() / 1000;
  status.total_samples = sampleSequence;
  status.oldest_buffered_seq = oldestSeq;
  status.newest_buffered_seq = newestSeq;
  status.buffered_count = bufferedCount;
  status.battery_pct = coarseBatteryPct(readBatteryMillivolts());
  status.flags = COMMUTA_FLAG_SHUTTING_DOWN;
  commutaBleUpdateStatus(status);
  Serial.printf("Shutdown: sent SHUTTING_DOWN status (buf=%u, newest=%u)\n",
                (unsigned)bufferedCount, (unsigned)newestSeq);
  delay(300);  // generous window for the notification to actually leave the radio

  // Clean sensor stop. SPS30 in particular benefits from stopMeasurement
  // (its fan spins down and the laser turns off cleanly).
  Serial.println("Shutdown: stopping sensors");
  sps30.stopMeasurement();
  scd4x.stopPeriodicMeasurement();

  // CRITICAL: wait for button release before sleeping. If we enter deep
  // sleep with GPIO27 still LOW, EXT0 wakes the chip back up immediately.
  Serial.println("Shutdown: waiting for button release");
  while (digitalRead(PIN_BUTTON) == LOW) delay(10);
  delay(COMMUTA_BTN_DEBOUNCE_MS);

  ledOff();
  Serial.println("Shutdown: entering deep sleep");
  enterDeepSleep();
  // unreachable
}
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
void loop() {
  // Service button gestures every iteration. Cheap (one digitalRead + a
  // bit of state-machine arithmetic).
  commutaButtonUpdate();

  // SGP41 must be sampled at ~1 Hz for the gas index algorithm to track properly.
  if (millis() - lastSgp41Ms >= SGP41_SAMPLE_INTERVAL_MS) {
    lastSgp41Ms = millis();
    sampleSgp41();
  }

  // Service buffered-sync streaming. Runs every loop iteration; cheap when
  // no sync is active. Sends at most one BLE notification per call so the
  // main loop stays responsive.
  commutaBleServiceSync();

  // Print sensors and notify BLE every PRINT_INTERVAL_MS.
  if (millis() - lastPrint < PRINT_INTERVAL_MS) return;
  lastPrint = millis();
  Serial.println("-----------------------------");

  // --- SPS30 ---
  float pm1, pm25, pm4, pm10;
  float nc05, nc1, nc25, nc4, nc10;
  float tps;
  if (sps30.readMeasurementValuesFloat(pm1, pm25, pm4, pm10,
                                       nc05, nc1, nc25, nc4, nc10, tps)) {
    Serial.println("SPS30: No reading");
  } else {
    latestPm1 = pm1;
    latestPm25 = pm25;
    latestPm10 = pm10;
    Serial.print("PM1.0: ");
    Serial.print(pm1);
    Serial.println(" ug/m3");
    Serial.print("PM2.5: ");
    Serial.print(pm25);
    Serial.println(" ug/m3");
    Serial.print("PM4.0: ");
    Serial.print(pm4);
    Serial.println(" ug/m3");
    Serial.print("PM10:  ");
    Serial.print(pm10);
    Serial.println(" ug/m3");
  }

  // --- SCD40 ---
  uint16_t co2 = 0;
  float t = 0.0f, rh = 0.0f;
  bool ready = false;
  scd4x.getDataReadyStatus(ready);
  if (ready) {
    scd4x.readMeasurement(co2, t, rh);
    latestCo2 = co2;
    latestT = t;
    latestRh = rh;
    haveScdReading = true;
    Serial.print("CO2:  ");
    Serial.print(co2);
    Serial.println(" ppm");
    Serial.print("Temp: ");
    Serial.print(t);
    Serial.println(" C");
    Serial.print("Hum:  ");
    Serial.print(rh);
    Serial.println(" %");
  } else {
    Serial.println("SCD40: No reading yet");
  }

  // --- DPS368 ---
  Adafruit_Sensor* dps_pressure = dps.getPressureSensor();
  Adafruit_Sensor* dps_temp = dps.getTemperatureSensor();
  sensors_event_t pe, te;
  // NOTE: gate on pressureAvailable() FIRST. In the Adafruit DPS310/DPS368
  // driver a single getEvent() reads the whole PSR+TMP register block and
  // clears BOTH data-ready flags, so checking temperatureAvailable() before
  // the pressure read would clear PRS_RDY and make us skip pressure. Reading
  // pressure first, then temperature, keeps both readings valid: the temp
  // getEvent() below re-reads the (still-fresh) register block.
  if (dps.pressureAvailable()) {
    dps_pressure->getEvent(&pe);
    latestPressure = pe.pressure;
    Serial.print("Pressure: ");
    Serial.print(pe.pressure);
    Serial.println(" hPa");

    // DPS368 ambient temperature. Unlike the SCD40 (NDIR self-heater, whose
    // reading drifts upward as the enclosure warms), the DPS368 has no
    // internal heater and tracks sensor-chamber air temperature honestly, so
    // it is what we report as ambient over BLE. The DPS368 was already
    // measuring temperature internally for its own pressure compensation;
    // this just surfaces that value. SCD40 temperature is still logged in
    // the sample (feeds SGP41 T/RH comp + methodology metadata).
    dps_temp->getEvent(&te);
    latestDps368Temp = te.temperature;
    Serial.print("DPS Temp: ");
    Serial.print(te.temperature);
    Serial.println(" C");

    // Feed ambient pressure to the SCD40 for CO2 compensation. The SCD40
    // applies this internally until changed, so we refresh at least every
    // PRESSURE_COMP_INTERVAL_MS, or sooner on a >5 hPa move. setAmbientPressure
    // takes Pa (per the SensirionI2cScd4x header) and may be sent during
    // periodic measurement. latestPressure is logged in every sample below,
    // so the compensation reference is recorded for reproducibility.
    bool due = (millis() - lastPressureCompMs) >= PRESSURE_COMP_INTERVAL_MS;
    bool jumped = fabsf(latestPressure - lastPressureCompHpa) >= PRESSURE_COMP_DELTA_HPA;
    if (latestPressure > 0.0f && (due || jumped)) {
      uint32_t pa = (uint32_t)(latestPressure * 100.0f + 0.5f);  // hPa -> Pa
      int16_t perr = scd4x.setAmbientPressure(pa);
      if (perr) {
        Serial.printf("SCD40: setAmbientPressure(%u Pa) err %d\n",
                      (unsigned)pa, perr);
      } else {
        Serial.printf("SCD40: ambient pressure -> %u Pa (%.1f hPa)\n",
                      (unsigned)pa, latestPressure);
        lastPressureCompMs = millis();
        lastPressureCompHpa = latestPressure;
      }
    }
  } else {
    Serial.println("DPS368: No reading yet");
  }

  // --- SGP41 ---
  bool conditioning = (millis() - sgp41StartMs) < SGP41_CONDITIONING_MS;
  Serial.print("SRAW VOC: ");
  Serial.println(srawVoc);
  Serial.print("VOC Idx:  ");
  Serial.println(vocIndex);
  if (conditioning) {
    Serial.println("SRAW NOx: (conditioning)");
    Serial.println("NOx Idx:  (conditioning)");
  } else {
    Serial.print("SRAW NOx: ");
    Serial.println(srawNox);
    Serial.print("NOx Idx:  ");
    Serial.println(noxIndex);
  }

  // --- Build the sample, persist it, and notify BLE ---
  uint16_t vbatMv = readBatteryMillivolts();

  CommutaSample sample = {};
  sample.struct_version = COMMUTA_STRUCT_VERSION;
  sample.boot_epoch = bootEpoch;
  sample.sequence = sampleSequence++;
  sample.pm1 = latestPm1;
  sample.pm25 = latestPm25;
  sample.pm10 = latestPm10;
  sample.co2 = latestCo2;
  sample.temperature = latestT;
  sample.humidity = latestRh;
  sample.pressure = latestPressure;
  sample.dps368_temp_c = latestDps368Temp;
  sample.sraw_voc = srawVoc;
  sample.sraw_nox = srawNox;
  sample.voc_index = (int16_t)vocIndex;
  sample.nox_index = (int16_t)noxIndex;
  sample.vbat_mv = vbatMv;
  sample.flags = conditioning ? COMMUTA_FLAG_CONDITIONING : 0;

  // Persist to flash first, then notify the Live characteristic.
  commutaStorageAppend(sample);
  commutaBleNotifyLive(sample);

  // --- Update Status characteristic ---
  uint32_t oldestSeq, newestSeq, bufferedCount;
  commutaStorageGetRange(oldestSeq, newestSeq, bufferedCount);

  CommutaStatus status = {};
  status.uptime_seconds = millis() / 1000;
  status.total_samples = sampleSequence;
  status.oldest_buffered_seq = oldestSeq;
  status.newest_buffered_seq = newestSeq;
  status.buffered_count = bufferedCount;
  status.battery_pct = coarseBatteryPct(vbatMv);
  status.flags = sample.flags & COMMUTA_FLAG_CONDITIONING;
  commutaBleUpdateStatus(status);

  Serial.print("Bat:  ");
  Serial.print(vbatMv);
  Serial.print(" mV  Buf: ");
  Serial.print(bufferedCount);
  Serial.print("  BLE: ");
  Serial.println(commutaBleIsConnected() ? "connected" : "advertising");
}

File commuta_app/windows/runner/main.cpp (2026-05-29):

#include <flutter/dart_project.h>
#include <flutter/flutter_view_controller.h>
#include <windows.h>

#include "flutter_window.h"
#include "utils.h"

int APIENTRY wWinMain(_In_ HINSTANCE instance, _In_opt_ HINSTANCE prev,
                      _In_ wchar_t *command_line, _In_ int show_command) {
  // Attach to console when present (e.g., 'flutter run') or create a
  // new console when running with a debugger.
  if (!::AttachConsole(ATTACH_PARENT_PROCESS) && ::IsDebuggerPresent()) {
    CreateAndAttachConsole();
  }

  // Initialize COM, so that it is available for use in the library and/or
  // plugins.
  ::CoInitializeEx(nullptr, COINIT_APARTMENTTHREADED);

  flutter::DartProject project(L"data");

  std::vector<std::string> command_line_arguments =
      GetCommandLineArguments();

  project.set_dart_entrypoint_arguments(std::move(command_line_arguments));

  FlutterWindow window(project);
  Win32Window::Point origin(10, 10);
  Win32Window::Size size(1280, 720);
  if (!window.Create(L"commuta_app", origin, size)) {
    return EXIT_FAILURE;
  }
  window.SetQuitOnClose(true);

  ::MSG msg;
  while (::GetMessage(&msg, nullptr, 0, 0)) {
    ::TranslateMessage(&msg);
    ::DispatchMessage(&msg);
  }

  ::CoUninitialize();
  return EXIT_SUCCESS;
}

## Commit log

2026-05-23 Updated Wiring pictures
2026-05-29 Flutter-based app with top and bottom bars
    Commuta App is the corresponding visualisation app to the Commuta air monitor device.
    The app contains an animated bottom bar with four tabs and a top status bar.
2026-06-04 pcb code
2026-06-08 Home screen update
    Add scale appearances for each air quality data
    Add the absolute air pressure change card
    Change the hero DAQI card to an overall air quality card
2026-06-08 Map screen update
    Google Map & TFL map toggle button
    Integrate Google Map to the map screen
    Render the map with real-time location
    Markers on the reading location
2026-06-14 Physical device raw data
    All sensors output raw data every 10 seconds
    GPIO pin changed for DPS368
2026-06-24 Enclosure designs
    [Annie_Commuta_test2_bottom.stl, Annie_Commuta_test2_top.stl, Commuta_Bottom_Two_holes.stl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]
2026-06-24 Add LittleFS sample buffering and BLE buffered-sync streaming for untethered operation across reboots and reconnects
    [Commuta_code.ino, ble.cpp, ble.h]
2026-06-26 Button and LED firmware design
    Features: device on/off; sensors check; finish the current data sync while shutdown.
    [Commuta_Botton_2Holes.stl, Commuta_Top_2Holes.stl]
2026-06-30 App-side BLE and enclosure designs
    [Commuta_Bottom_version8.stl, Commuta_Draft8.stl, Commuta_Draft9.stl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]
2026-07-01 Commuta PCB designs
2026-07-06 BLE sync bug fix
    [ble.cpp]
2026-07-07 Data export through Profile tab
    CSV Export: today only or all data. The csv file contains 21 columns: sequence_number, timestamp, pm1, pm2.5, pm10, co2, temperature, humidity, pressure, pressure_change_pa_per_sec, nox, tvoc, voc_ra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
2026-07-10 Data visualisation
    [commuta_readings_20260710.xlsx]
2026-07-31 Firmware correction
    Firmware: raw battery voltage instead of estimated battery percentage for more accurate estimation on the app side;
    SCD40 pressure compensation from DPS368;
    SGP41 temperature and humidity compensation from SCD40;
    Print out DPS368 temperature reading.
    [Commuta_code.ino, ble.h]
2026-07-31 App updates for sensor correction and battery estimation
    Parser rewritten to the 50-byte layout;
    Add DPS_tem column in CSV exported data;
    A temporary battery characterisation form to adjust the accuracy of battery estimation
2026-08-02 Lipo battery discharge characterisation analysis
    [commuta_battery_characterisation_20260802_004327.csv, voltage_percentage_lookup.csv]
2026-08-07 Battery UI update
2026-08-16 Raw data for 6 TFL lines
    [commuta_readings_today_20260710_114808.csv, commuta_readings_today_20260807_233732.csv, commuta_readings_today_20260810_184020.csv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]
2026-08-16 Processed data using Python
    commuta_clean.csv, one big clean data set for 6 TFL lines, each has two data collection journeys. Rerunning the process_data.py file on raw data and 2 metadata files can reproduce the clean dataset.
    [commuta_clean.csv, corrections.csv, segments.csv]
2026-08-17 More plots for data analysis
    [Data_Collection_Journeys.xlsx, commuta_section4_medians.xlsx, commuta_stops.csv]
2026-08-21 Battery estimation correction
    [commuta_section4_medians.xlsx, voltage_percentage_lookup (1).csv, voltage_percentage_lookup.csv]
2026-08-25 Breadboard photos
    [PMS breadboard.fzz, SPS30breadboard.fzz]
